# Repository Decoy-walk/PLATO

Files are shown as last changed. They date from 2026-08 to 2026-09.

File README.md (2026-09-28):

# PLATO — Embodied Memory via Material Interaction

*[한국어](README.ko.md)*

Research prototype for testing whether tactile-motor interaction with a
physical folding-block device activates procedural memory as a
supplementary channel, improving recall vs. text-only encoding. A sensing
node embedded in the folding block tracks all 20 hinges and streams the
fold state over wired USB serial to a PC bridge that logs it to CSV, git,
and/or a Google Sheet.

```
 hand  ⇄  folding block (20 flex-sensor hinges + haptic actuator)
                 │  USB serial (~20 Hz, framed 4-byte fold bitmask)
                 ▼
         bridge/plato_bridge.py  (PC)
                 │
        ┌────────┼─────────┐
        ▼        ▼         ▼
   data/*.csv   git commit   Google Sheets
```

## Hardware

| Component | Role |
|---|---|
| Seeed XIAO SAMD21 | MCU: scans the 20 hinges, drives haptic feedback, streams over USB |
| 20× flex sensor (one per hinge)  | Captures the fold sequence as the hand manipulates the block |
| 2× CD74HC4067 (16-channel analog mux) | Multiplexes 20 flex-sensor channels onto 1 ADC pin |
| Haptic/ERM motor + driver transistor | "Block + haptic feedback" condition's feedback channel |

The board was originally ESP32C3 (see git history) and moved permanently to
SAMD21. SAMD21 has no on-board radio, so wireless logging is an open
question — see "Wireless is still undecided" below — and this build uses a
wired USB serial connection as the interim transport.

### Why a mux instead of more ADC pins or an I2C ADC expander

Neither ESP32C3 nor SAMD21's XIAO form factor exposes 20 native ADC pins.
Rather than adding 5× I2C ADC boards (e.g. ADS1115), this design keeps the
channel count matched to what the board can actually do: two CD74HC4067
16-channel analog muxes (32 channels available, 20 used) share 4 address
lines and time-multiplex all 20 flex sensors onto a **single** ADC pin.
Only one mux's active-low `EN` is driven low at a time; the other's output
stays high-impedance, so both chips' common `SIG` pins can tie to the same
ADC input. Net cost: 1 ADC pin + 6 digital GPIO instead of 20 ADC pins or
extra I2C ADC hardware. (SAMD21 actually has no ADC-vs-radio pin
restriction the way ESP32C3's ADC2 did, but the mux wiring is kept
identical for continuity with the physical harness.)

### Pins (Seeed XIAO SAMD21 silkscreen labels)

| Function | XIAO pin | Notes |
|---|---|---|
| Mux common analog output | D0 (A0)  | Both CD74HC4067 `SIG` pins tie here |
| Mux address S0 | D1 | Shared between both mux chips |
| Mux address S1 | D2 | |
| Mux address S2 | D3 | |
| Mux address S3 | D4 | |
| Mux A enable (active-low) | D5 | Selects hinges 0-15 |
| Mux B enable (active-low) | D6 | Selects hinges 16-19 (channels 4-15 of mux B unused) |
| Haptic actuator PWM | D7 | To a transistor driving the ERM/LRA motor (+ flyback diode) |
| Status LED | D10 | Lit while any hinge reads folded |

Each flex sensor forms its own voltage divider into its mux channel:
`3V3 — flexSensor — muxChannel — 10kΩ — GND`. Both mux chips' `S0-S3` are
wired in parallel; `EN` pins are separate so the firmware can choose which
16-channel bank is currently driving the shared `SIG`/ADC line.

## Two separate firmware builds

- `firmware/PLATO_XIAO_SAMD21/` — the research build described below
  (SAMD21, 20-hinge sensing, wired serial, PC bridge).
- `firmware/Plato_001_fsr_led/` — the actual circuit exhibited at Maker
  Faire Tokyo 2026 (Sep 4-8): one FSR402 + one LED on a bare XIAO SAMD21,
  built for "E. Modular" (a FidgetSqueezer-style folding ball — see
  `hardware/cad/` and `hardware/docs/MFT26_devlog.pdf`). See its own README for
  the exact breadboard wiring. Kept separate from the research firmware
  since it's a different physical object (a single squeeze-force joint,
  not 20 independently-sensed hinges) built for a specific exhibition
  deadline, not the formal study.
- `firmware/Plato_002_fsr_led_buzzer_vibration/` — post-exhibition
  extension of `Plato_001_fsr_led`: adds a TMB12A05 active buzzer (5V,
  fixed ~2.4kHz, pulsed into chirps) above a squeeze-force threshold, and
  an ERM vibration-motor module whose intensity scales continuously with
  press force (a graded haptic "feel the resonance plate vibrating" layer,
  not just on/off). `Plato_001_fsr_led` is left untouched as the
  historical record of what actually showed at Maker Faire; new sensory
  layers land in their own numbered sketch instead.
- `firmware/Plato_003_fsr_led_buzzer/` — same as `Plato_002` minus the
  vibration motor module, for when only sound feedback is wanted.

## Firmware (`firmware/PLATO_XIAO_SAMD21/`)

```
PLATO_XIAO_SAMD21.ino  # setup/loop, serial commands, condition toggling
config.h                # pins, mux/timing/haptic constants, serial framing
FlexMuxManager.*        # mux channel scanning, per-hinge calibration (RAM-only), fold bitmask
HapticManager.*         # non-blocking haptic pulse control
SerialTransport.*       # wired USB serial framing (interim - see below)
sketch.yaml             # arduino-cli profile (board + platform version)
```

### Wireless is still undecided

SAMD21 has no BLE/Wi-Fi radio. Two options were on the table:

1. **Wired USB serial** (what's implemented now) — zero extra hardware,
   most reliable, but reintroduces the "does a cable undermine the
   naturalistic-interaction claim" concern raised for the write-up.
2. **External BLE UART module** (e.g. a DA14531/nRF52-based UART-BLE
   bridge) — keeps the wireless/naturalistic-use framing intact at the
   cost of extra per-node hardware and wiring.

`SerialTransport` is deliberately the only place that knows about the wire
protocol — `PLATO_XIAO_SAMD21.ino` just calls `transport.send(payload, len)`.
Swapping in a `BleUartTransport` later (same `send()` signature, framed
over a BLE UART module's serial passthrough instead of the native USB port)
should be a small, isolated change, not a rewrite.

### Calibration (per-hinge variance)

Flex-sensor voltage-divider output varies hinge-to-hinge (resistance range,
mounting preload). Rather than a single global threshold, each hinge gets
its own calibrated min/max:

- Send `c` over the serial monitor to start a 15 s calibration window
  (`CALIBRATION_DURATION_MS`); fold/unfold every hinge through its full
  range while it runs.
- Calibration is **RAM-only** (SAMD21 has no direct equivalent to ESP32's
  `Preferences`/NVS without another library dependency) and is printed
  per-hinge, so you have a `min/max/range` table to report alongside the
  data — the explicit bounding of per-hinge variance flagged as an
  internal-validity concern for the write-up. Because it's RAM-only, **run
  `c` again after every power cycle** — this matches the documented
  per-session calibration protocol anyway (run once per session/participant
  rather than trusting a stale factory default).

### Condition toggling

`h` over serial toggles haptic feedback on/off at runtime, so the same
flashed firmware serves both the **Block (motor only)** and **Block +
haptic feedback** study arms without reflashing between participants. The
condition flag is included in every serial frame (see below) so it's
logged automatically rather than needing to be tracked by hand.

### Serial frame format

Every `NOTIFY_INTERVAL_MS` (20 Hz default) the node writes a 6-byte frame
to the USB serial port: 2 marker bytes (so the PC-side reader can
byte-align on this continuous stream even if it connects mid-frame, and
self-heal from an occasional dropped/corrupted byte) followed by the same
4-byte payload the ESP32C3 build used to send over BLE:

| Byte | Content |
|---|---|
| 0 | `0xAA` sync byte 1 |
| 1 | `0x55` sync byte 2 |
| 2-4  | 20-bit fold bitmask, LSB first (bit *i* = hinge *i* folded) |
| 5 | bit0: haptic pulse currently firing · bit1: haptic-feedback condition enabled |

### Setup

```bash
arduino-cli config add board_manager.additional_urls \
  https://files.seeedstudio.com/arduino/package_seeeduino_boards_index.json
arduino-cli core update-index
arduino-cli core install Seeeduino:samd
```

`sketch.yaml` pins the board/platform version; with arduino-cli >= 0.35 the
`--profile` flag (used by the scripts below) installs and uses it
automatically. No external libraries are needed (Arduino SAMD core only).

In Arduino IDE: Tools > Board > **Seeed SAMD Boards > Seeeduino XIAO**.

### Build & flash

```bash
scripts/build.sh
scripts/upload.sh /dev/ttyACM0   # adjust to your board's serial port
scripts/monitor.sh /dev/ttyACM0
```

## PC bridge (`bridge/`)

The node streams over wired USB serial (see "Wireless is still undecided"
above); the bridge opens that port directly and fans each reading out to a
local CSV, an optional git commit+push, and/or a Google Sheet.

```bash
pip install -r bridge/requirements.txt

# CSV only:
python bridge/plato_bridge.py --ports /dev/ttyACM0

# CSV + auto-commit every 50 rows + push to Google Sheets:
python bridge/plato_bridge.py \
  --ports /dev/ttyACM0 \
  --git-commit-every 50 \
  --sheets-url "https://script.google.com/macros/s/XXXX/exec"
```

- `--ports` (default `/dev/ttyACM0`): comma-separated serial port(s), one
  per physical node — each runs in its own thread, so multiple structures
  just means multiple `--ports` entries (e.g. `/dev/ttyACM0,/dev/ttyACM1`).
- `--baud` (default 115200): must match `SERIAL_BAUD` in `config.h`.
- `--csv` (default `data/plato_log.csv`): one row per frame, columns
  `timestamp_utc,node,haptic_active,haptic_enabled,hinge_00..hinge_19`.
  Logging every snapshot (not just transitions) means one corrupted/lost
  frame never loses an event — fold-sequence order and per-hinge transition
  timing (for the Kendall's Tau / Spearman's rho / edit-distance analyses)
  are reconstructed from the time series afterward, not relied on from the
  stream itself.
- `--git-commit-every N`: commit+push the CSV every N new rows (0 disables).
  Requires the bridge to run somewhere with push access to this repo.
- `--sheets-url` / `GOOGLE_SHEETS_WEBHOOK_URL`: POSTs each row as JSON to a
  Google Apps Script Web App. See `bridge/google_apps_script.gs` for the
  script to paste into a target Sheet's Apps Script editor and deploy as a
  Web App (Extensions → Apps Script → Deploy → New deployment).

If a node disconnects mid-session, restart the bridge — it's a straight
open-and-stream loop per port, no reconnect logic yet.

## Extending

- Multiple structures/nodes: connect each over its own USB port and add it
  to `--ports`; the bridge already fans in every port concurrently.
- More/fewer hinges: `FlexMuxManager::kChannelCount` and the mux wiring
  scale to any count up to 32 (two 16-channel muxes) without firmware
  changes beyond that constant. Keep any CAD change to hinge count in sync
  with this constant (see `hardware/cad/README.md`).
- Adding wireless: implement a `BleUartTransport` with the same
  `send(data, len)` signature as `SerialTransport` and swap it in
  `PLATO_XIAO_SAMD21.ino` — the rest of the firmware doesn't need to change.

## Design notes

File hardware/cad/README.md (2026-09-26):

# CAD (Fusion 360 exports)

Fusion 360's native cloud file (`.f3d`) isn't meaningful to version in git — it's
an opaque binary tied to Autodesk's own cloud/version history, not diffable
here. Instead, export a neutral format from Fusion 360 at each milestone and
commit that:

| Format | Use for |
|---|---|
| `.step` / `.stp` | Full solid model (hinges, sensor mounts, enclosure) — preferred for anything meant to be re-opened/edited in other CAD tools |
| `.stl` | 3D-printable mesh of the current print-ready state |
| `.dxf` | 2D profiles (e.g. laser-cut hinge plates) if any part of the block is flat-stock |

## Naming convention

```
plato-block_v<major>.<minor>_<yyyy-mm-dd>.step
```

e.g. `plato-block_v0.3_2026-08-27.step`. Bump `major` on a structural change
(hinge count, layout), `minor` on a dimensional tweak (wall thickness, mount
hole size).

## Keeping CAD and firmware in sync

The physical hinge count/layout and `firmware/PLATO_XIAO_SAMD21/config.h` /
`FlexMuxManager::kChannelCount` need to agree. When exporting a new revision
that changes hinge count or numbering order, note it in the commit message
and update `kChannelCount` (and the mux wiring notes in the top-level
`README.md`) in the same PR so the two never drift apart silently.

## Wiring diagrams

Two DXF diagrams cover the same `firmware/Plato_002_fsr_led_buzzer_vibration/`
circuit (XIAO SAMD21, FSR402 voltage divider, LED, buzzer, vibration motor
module), for two different physical breadboards. Both are generated with
[ezdxf](https://ezdxf.mozman.at/) as plain vector geometry on named layers —
open either via **Insert > Insert DXF** into a Fusion 360 sketch (or any
other DXF-reading tool). Neither is a to-scale footprint layout; for the
exact row-by-row wiring instructions, see `firmware/Plato_001_fsr_led/README.md`
and `firmware/Plato_002_fsr_led_buzzer_vibration/README.md`.

- **`plato_002_wiring_diagram.dxf`** — matches the **no-rail mini
  breadboard** the firmware READMEs document: 3V3/GND are net labels only,
  and every use of them is its own point-to-point jumper back to the chip
  (no shared rail exists on that board). Layers: `WIRES`, `COMPONENTS`,
  `RAILS`, `LABELS`.
- **`plato_002_wiring_diagram_shared_rail.dxf`** — redrawn for a
  **standard breadboard with real +/- power rails**: the chip only needs
  ONE jumper to the +rail and ONE to the -rail; every component taps the
  rail directly instead of getting its own dedicated wire back to the
  chip. Simpler to build if you're not constrained to the small no-rail
  board. Layers: `WIRES`, `COMPONENTS`, `RAIL_PLUS`, `RAIL_MINUS`, `LABELS`.

Pick whichever matches the physical breadboard actually on hand — they're
electrically equivalent, just wired differently.

## Adding a new export

From your local machine (this repo isn't checked out where Fusion 360 runs):

```bash
git add hardware/cad/plato-block_vX.Y_YYYY-MM-DD.step
git commit -m "Add CAD export vX.Y: <what changed>"
git push
```

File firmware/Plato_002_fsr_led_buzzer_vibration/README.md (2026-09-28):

# Plato_002_fsr_led_buzzer_vibration (Seeeduino XIAO, SAMD21)

Extends `Plato_001_fsr_led` (the circuit actually exhibited at Maker Faire
Tokyo 2026) with two more outputs, both active once the FSR is squeezed
past a threshold:

- A buzzer (TMB12A05) — a discrete on/off chirp layer (see below).
- A vibration-motor breakout module (driver built into the module) shaking
  hard enough to rattle the printed plastic structure against itself, and
  standing in for "feel the resonance plate vibrating" — its intensity
  scales continuously with how hard you press, not just on/off.

The FSR→LED brightness response is unchanged and stays continuously
proportional to force. The buzzer's chirp is a discrete on/off layer on
top, since "buzz" is a discrete effect, not something meaningfully swept
by force the way LED brightness is. The vibration motor, on the other
hand, is graded like the LED — see "Haptic feel" below.

## The buzzer is an active buzzer, not a passive piezo

TMB12A05 has a built-in driver and a fixed ~2.4kHz internal tone, rated
**4-8V (5V nominal)**. Two consequences that weren't obvious from the part
just looking like "a buzzer":

1. **Its pitch isn't settable.** `tone(pin, frequency)` only works on a bare
   passive piezo element; on an active buzzer like this one, any signal
   that turns it on just makes it sound at its own fixed ~2.4kHz — you
   can't dial in an arbitrary frequency.
2. **It needs 5V, not 3.3V, to reliably start.** Below its ~4V minimum, the
   internal driver likely won't oscillate at all — silence, not a quiet
   tone. Wiring its `+` lead to the XIAO's 3.3V rail (the natural thing to
   do next to the FSR/LED circuit, which does run at 3.3V) is almost
   certainly why the buzzer doesn't respond.

Since the MCU's GPIO HIGH is only 3.3V, it can't source the required 5V
either, so this build wires the buzzer as a **low-side switch**:

```
XIAO "5V" pin --------> buzzer + lead
buzzer - lead --------> D8
```

(The `5V` pin sources USB's raw 5V when the board is powered over USB —
this wiring only works while USB-powered, not on battery/regulated-3.3V-only
power.)

> **Lead identification: the SHORT lead is `+`, the LONG lead is `-`** —
> backwards from the LED long-leg-is-anode convention, easy to get wrong by
> habit. A printed `+` on the case can also fall off or be inconsistently
> placed, so trust lead length over any marking. Reversed polarity can
> prevent the buzzer from working at all.

For ON, `D8` is driven `OUTPUT` `LOW`, sinking current and completing the
circuit. For OFF, **`D8` is switched to `INPUT` (high-impedance)**, not
driven `HIGH` — driving it `HIGH` only leaves ~1.7V across the buzzer
(5V - 3.3V), and this particular buzzer's driver IC can *sustain*
oscillation at that leftover voltage even though it needs the full 4V+ to
*start* it, so a once-triggered buzzer never actually stopped when tried
with `HIGH` instead. Switching to `INPUT` removes the current path
entirely, which reliably silences it with no extra hardware. The firmware
does this (`pinMode(buzzerPin, OUTPUT/INPUT)` + `digitalWrite(buzzerPin, LOW)`
for ON, not `tone()`/`noTone()` and not a plain `HIGH` for OFF).

The buzzer draws ~30mA when on. Driving that directly through a GPIO pin as
a sink is common practice for a small load like this. If you have a small
NPN transistor (e.g. 2N3904) on hand, using it as a true low-side switch
(`D8` → base through a ~1kΩ resistor, buzzer `-` lead → collector, emitter
→ GND, control logic flipped back to `HIGH`=on) is an equally valid
alternative to the `INPUT`-for-off trick above and keeps current off the
MCU pin entirely — but isn't required to fix the "won't turn off" symptom.

## Making the buzzer sound less harsh (chirp pattern, no new hardware)

TMB12A05's ~2.4kHz tone is generated by its own internal driver IC — the
firmware has no control over that pitch or waveform at all (`tone()`'s
frequency argument does nothing here; see above). What the firmware *can*
control is the on/off **rhythm**: instead of holding the buzzer on
continuously for the whole press (one flat, harsh drone), it now pulses it
into short chirps while pressed — `BUZZ_ON_MS` (90ms) on, `BUZZ_OFF_MS`
(35ms) off, repeating — which reads as a beeping pattern rather than a
continuous industrial buzz. Each chirp's OFF gap still uses the same
`INPUT` high-impedance trick (not `HIGH`), so it's reliably silent between
chirps too.

An earlier, shorter version of this pattern (25ms on / 70ms off) came out
noticeably **quieter** than the old continuous tone, for two compounding
reasons: a low `ON/(ON+OFF)` duty cycle (26%) lowers the time-averaged
loudness on its own, and cutting the pulse at 25ms may also stop it before
the buzzer's internal driver finishes ramping up to full amplitude, so
each chirp never even reached full volume. 90/35 (72% duty) fixes both —
still audibly pulsing, not a flat drone, but full-volume and much louder.

This needed the main loop restructured from a single blocking `delay(50)`
per iteration to `millis()`-timed scheduling, so the buzzer can pulse
faster (down to a few ms) than the 50ms FSR/LED sampling rate allows —
sensor sampling and LED brightness are otherwise unchanged, still
effectively running at the same ~20Hz rate.

Tune `BUZZ_ON_MS` / `BUZZ_OFF_MS` in the `.ino` to taste: shorter ON / longer
OFF reads as a lighter "tick"; longer ON / shorter OFF drifts back towards a
continuous drone. **PWMing the sink pin** (partial duty via `analogWrite`
instead of full `LOW`/`INPUT`) was considered for a smoother fade, but
rejected: the leftover voltage during the `HIGH` portion of a PWM cycle can
re-trigger the exact "won't turn off" sustain behavior described above, so
this build only ever drives the pin fully `LOW` (on) or fully `INPUT` (off).

If you want a genuinely different pitch — e.g. closer to 600Hz — or a
smoother (less buzzy) waveform, that requires different hardware: swap this
active buzzer for a **passive piezo** (a 2-lead disc with no built-in
driver IC), which lets `tone(buzzerPin, 600)` set an arbitrary frequency
directly and runs fine off 3.3V (no `5V` pin/low-side-switch wiring needed
at all). That's a separate hardware change, not something this sketch's
software can do with the TMB12A05 installed.

## Haptic feel: force-proportional vibration, not on/off

The vibration motor module wraps a small **ERM (eccentric rotating mass)**
motor, not an LRA (linear resonant actuator). That distinction matters for
how it's driven:

- An LRA is driven at (or swept across) a specific resonant frequency, and
  its *frequency* is the tunable knob.
- An ERM has no such tunable frequency. What you feel as its "buzz
  frequency" is just how fast the offset weight is spinning, which tracks
  the applied voltage/PWM duty directly — there's no separate frequency
  control, only a speed/intensity control.

Small coin ERM motors also typically need roughly **60-70% of their rated
voltage just to start spinning at all** (they have to overcome their own
static friction/cogging) — below that they don't spin, so they give no
felt vibration rather than a gentler one. That makes a naive full 0-255
PWM sweep (like the LED's brightness mapping) mostly waste: most of that
range would either not move the motor or move it so weakly it can't be
felt.

So instead, once pressed, intensity is mapped from `MIN_EFFECTIVE_VIBRATION`
(170, ≈67% duty) up to `MAX_VIBRATION` (255) across the pressed force range
— never dropping into the ineffective low band — so a light press still
gives a felt, near-full-speed buzz and a hard press gives the strongest
one, rather than a binary "vibrating or not." This also keeps it running
close to its rated speed most of the time, which is roughly where small
coin ERM motors' felt vibration frequency sits — commonly cited around
**~150-200Hz** for this class of part at rated voltage, though that number
depends on the exact motor and isn't something this build measured
directly (re-check against a datasheet if you know this module's part
number).

## What this doesn't do yet: Chladni/Cymatics patterns

The original three-part plan also called for mapping the sound to visible
Chladni-figure/Cymatics patterns. Neither this active buzzer (fixed
~2.4kHz, no frequency sweep possible) nor the ERM vibration motor has the
frequency control or power to drive visible nodal-line patterns in sand on
a plate — a real Chladni setup needs an amplified, frequency-swept signal
into a rigidly-mounted plate via a proper exciter/bass shaker. This build
treats the buzzer+vibration as a conceptual/experiential stand-in (press →
hear + feel + hear-the-structure-rattle) rather than a literal Chladni
demo. If a real visual pattern is wanted later, that's a separate hardware
addition (audio amp + exciter, or a software visualization driven by a mic
input) — flag it as its own task rather than folding it into this sketch.

## Wiring (no-rail mini breadboard)

Builds on the `Plato_001_fsr_led` breadboard (FSR on A0, LED on D9, rows
A-G — see that folder's README). This board has no shared power rails, so
every use of a supply voltage is its own point-to-point jumper back to its
source:

14. `D8` --jumper--> row H
15. Buzzer `-` lead (**long** lead) → row H
16. Buzzer `+` lead (**short** lead) → row I
17. XIAO `5V` pin --jumper--> row I
18. `D2` --jumper--> row J
19. Vibration module `IN` → row J
20. `3.3V-OUT` --jumper--> row K
21. Vibration module `VCC` → row K
22. `GND` --jumper--> row L
23. Vibration module `GND` → row L

**Buzzer** (TMB12A05, active, 2 leads): `+` (short) lead → row I (→ XIAO
`5V` pin), `-` (long) lead → row H (→ `D8`, `OUTPUT LOW`/`INPUT` switching — see above).

**Vibration motor module** (3-pin breakout, driver already on the board):
`D2` → `IN` (row J), `3V3` → `VCC` (row K, module is commonly rated 3-5V;
expect less punch at 3.3V than at 5V — try raising `MAX_VIBRATION` towards
255 (already its default) first before reaching for a 5V source), `GND` →
`GND` (row L).

## Wiring (standard breadboard with +/- power rails)

If you're not constrained to the no-rail mini board, a standard breadboard
with power rails is simpler to build: the chip needs only **one** jumper to
the +rail and **one** to the -rail total (plus the buzzer's dedicated 5V
jumper below, since that's a different voltage than the +rail), and every
other component taps a rail directly instead of getting its own dedicated
wire back to the chip. See `hardware/cad/plato_002_wiring_diagram_shared_rail.dxf`
for the layout, which includes the buzzer's dedicated 5V feed.

1. `3.3V-OUT` --jumper--> breadboard **+rail**
2. `GND` --jumper--> breadboard **-rail**
3. FSR402 leg 1 → +rail; leg 2 → node C
4. 1kΩ resistor leg 1 → node C; leg 2 → -rail
5. `A0` --jumper--> node C (the divider tap point)
6. `D9` → 330Ω resistor leg 1; leg 2 → LED anode; LED cathode → -rail
7. XIAO `5V` pin → buzzer `+` lead (**short**); buzzer `-` lead (**long**) → `D8`
8. `D2` → vibration module `IN`
9. Vibration module `VCC` → +rail
10. Vibration module `GND` → -rail

## Tuning

- `PRESS_ON_BRIGHTNESS` / `PRESS_OFF_BRIGHTNESS` (40 / 20): hysteresis
  thresholds on the same 0-255 brightness scale as the LED — widen the gap
  if the buzzer/vibration chatter on and off near the threshold.
- `MIN_EFFECTIVE_VIBRATION` / `MAX_VIBRATION` (170 / 255): the PWM range the
  vibration module's `IN` pin is scaled across while pressed — see "Haptic
  feel" above. Raise `MIN_EFFECTIVE_VIBRATION` if a light press still
  doesn't spin the motor at all; lower it (cautiously) if you want a
  softer floor and your motor tolerates it.
- `BUZZ_ON_MS` / `BUZZ_OFF_MS` (90 / 35): the buzzer's chirp pattern while
  pressed — see "Making the buzzer sound less harsh" above. Raise `BUZZ_ON_MS`
  and/or lower `BUZZ_OFF_MS` for louder/more continuous; lower `BUZZ_ON_MS`
  and/or raise `BUZZ_OFF_MS` for softer/more clearly pulsed. Practical
  bench-tested bounds (not datasheet specs — TMB12A05 doesn't publish
  ramp-up/decay times):
  - `BUZZ_ON_MS` below ~40-50ms: driver may cut off before reaching full
    volume (this is what made the original 25ms version sound quiet/thin).
    Above ~150-200ms: no technical ceiling, but it starts reading as one
    continuous tone rather than distinct beeps.
  - `BUZZ_OFF_MS` at 0: reverts to the original harsh continuous drone
    (no audible gap at all). Below ~15-20ms: the buzzer's diaphragm may not
    fully settle before the next pulse starts, so the gap barely registers.
    Above ~300-500ms: reads as separate, clearly spaced clicks, and a very
    short press can end before a single chirp completes.

  | Goal | ON / OFF (ms) | Duty |
  |------|---------------|------|
  | Softest (ok if quiet) | 40 / 150 | ~21% |
  | Current default (balanced) | 90 / 35 | ~72% |
  | Loud, distinct beeps | 120 / 60 | ~67% |
  | Near-continuous (loud, harsh) | 200 / 10 | ~95% |

## Setup / build / flash

Same as `Plato_001_fsr_led` — see that folder's README (Seeeduino:samd
board package, no external libraries).

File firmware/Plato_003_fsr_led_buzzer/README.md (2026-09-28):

# Plato_003_fsr_led_buzzer (Seeeduino XIAO, SAMD21)

Extends `Plato_001_fsr_led` (the circuit actually exhibited at Maker Faire
Tokyo 2026) with one more output, triggered when the FSR is squeezed past
a threshold: a buzzer (TMB12A05). Same as
`Plato_002_fsr_led_buzzer_vibration` but **without the vibration motor
module** — use this if you only want sound feedback.

The FSR→LED brightness response is unchanged and stays continuously
proportional to force; the buzzer is a separate on/off layer on top, since
"buzz" is a discrete effect, not something meaningfully swept by force the
way LED brightness is.

## The buzzer is an active buzzer, not a passive piezo

TMB12A05 has a built-in driver and a fixed ~2.4kHz internal tone, rated
**4-8V (5V nominal)**. Two consequences that weren't obvious from the part
just looking like "a buzzer":

1. **Its pitch isn't settable.** `tone(pin, frequency)` only works on a bare
   passive piezo element; on an active buzzer like this one, any signal
   that turns it on just makes it sound at its own fixed ~2.4kHz — you
   can't dial in an arbitrary frequency.
2. **It needs 5V, not 3.3V, to reliably start.** Below its ~4V minimum, the
   internal driver likely won't oscillate at all — silence, not a quiet
   tone. Wiring its `+` lead to the XIAO's 3.3V rail (the natural thing to
   do next to the FSR/LED circuit, which does run at 3.3V) is almost
   certainly why a buzzer wired that way doesn't respond.

Since the MCU's GPIO HIGH is only 3.3V, it can't source the required 5V
either, so this build wires the buzzer as a **low-side switch**:

```
XIAO "5V" pin --------> buzzer + lead
buzzer - lead --------> D8
```

(The `5V` pin sources USB's raw 5V when the board is powered over USB —
this wiring only works while USB-powered, not on battery/regulated-3.3V-only
power.)

> **Lead identification: the SHORT lead is `+`, the LONG lead is `-`** —
> backwards from the LED long-leg-is-anode convention, easy to get wrong by
> habit. A printed `+` on the case can also fall off or be inconsistently
> placed, so trust lead length over any marking. Reversed polarity can
> prevent the buzzer from working at all.

For ON, `D8` is driven `OUTPUT` `LOW`, sinking current and completing the
circuit. For OFF, **`D8` is switched to `INPUT` (high-impedance)**, not
driven `HIGH` — driving it `HIGH` only leaves ~1.7V across the buzzer
(5V - 3.3V), and this particular buzzer's driver IC can *sustain*
oscillation at that leftover voltage even though it needs the full 4V+ to
*start* it, so a once-triggered buzzer never actually stopped when tried
with `HIGH` instead. Switching to `INPUT` removes the current path
entirely, which reliably silences it with no extra hardware. The firmware
does this (`pinMode(buzzerPin, OUTPUT/INPUT)` + `digitalWrite(buzzerPin, LOW)`
for ON, not `tone()`/`noTone()` and not a plain `HIGH` for OFF).

The buzzer draws ~30mA when on. Driving that directly through a GPIO pin as
a sink is common practice for a small load like this. If you have a small
NPN transistor (e.g. 2N3904) on hand, using it as a true low-side switch
(`D8` → base through a ~1kΩ resistor, buzzer `-` lead → collector, emitter
→ GND, control logic flipped back to `HIGH`=on) is an equally valid
alternative to the `INPUT`-for-off trick above and keeps current off the
MCU pin entirely — but isn't required to fix the "won't turn off" symptom.

## Making the buzzer sound less harsh (chirp pattern, no new hardware)

TMB12A05's ~2.4kHz tone is generated by its own internal driver IC — the
firmware has no control over that pitch or waveform at all (`tone()`'s
frequency argument does nothing here; see above). What the firmware *can*
control is the on/off **rhythm**: instead of holding the buzzer on
continuously for the whole press (one flat, harsh drone), it now pulses it
into short chirps while pressed — `BUZZ_ON_MS` (90ms) on, `BUZZ_OFF_MS`
(35ms) off, repeating — which reads as a beeping pattern rather than a
continuous industrial buzz. Each chirp's OFF gap still uses the same
`INPUT` high-impedance trick (not `HIGH`), so it's reliably silent between
chirps too.

An earlier, shorter version of this pattern (25ms on / 70ms off) came out
noticeably **quieter** than the old continuous tone, for two compounding
reasons: a low `ON/(ON+OFF)` duty cycle (26%) lowers the time-averaged
loudness on its own, and cutting the pulse at 25ms may also stop it before
the buzzer's internal driver finishes ramping up to full amplitude, so
each chirp never even reached full volume. 90/35 (72% duty) fixes both —
still audibly pulsing, not a flat drone, but full-volume and much louder.

This needed the main loop restructured from a single blocking `delay(50)`
per iteration to `millis()`-timed scheduling, so the buzzer can pulse
faster (down to a few ms) than the 50ms FSR/LED sampling rate allows —
sensor sampling and LED brightness are otherwise unchanged, still
effectively running at the same ~20Hz rate.

Tune `BUZZ_ON_MS` / `BUZZ_OFF_MS` in the `.ino` to taste: shorter ON / longer
OFF reads as a lighter "tick"; longer ON / shorter OFF drifts back towards a
continuous drone. **PWMing the sink pin** (partial duty via `analogWrite`
instead of full `LOW`/`INPUT`) was considered for a smoother fade, but
rejected: the leftover voltage during the `HIGH` portion of a PWM cycle can
re-trigger the exact "won't turn off" sustain behavior described above, so
this build only ever drives the pin fully `LOW` (on) or fully `INPUT` (off).

If you want a genuinely different pitch — e.g. closer to 600Hz — or a
smoother (less buzzy) waveform, that requires different hardware: swap this
active buzzer for a **passive piezo** (a 2-lead disc with no built-in
driver IC), which lets `tone(buzzerPin, 600)` set an arbitrary frequency
directly and runs fine off 3.3V (no `5V` pin/low-side-switch wiring needed
at all). That's a separate hardware change, not something this sketch's
software can do with the TMB12A05 installed.

## Wiring (no-rail mini breadboard)

Builds on the `Plato_001_fsr_led` breadboard (FSR on A0, LED on D9, rows
A-G — see that folder's README). This board has no shared power rails, so
every use of a supply voltage is its own point-to-point jumper back to its
source:

14. `D8` --jumper--> row H
15. Buzzer `-` lead (**long** lead) → row H
16. Buzzer `+` lead (**short** lead) → row I
17. XIAO `5V` pin --jumper--> row I

**Buzzer** (TMB12A05, active, 2 leads): `+` (short) lead → row I (→ XIAO
`5V` pin), `-` (long) lead → row H (→ `D8`, `OUTPUT LOW`/`INPUT` switching — see above).

## Wiring (standard breadboard with +/- power rails)

If you're not constrained to the no-rail mini board: the chip needs only
**one** jumper to the +rail and **one** to the -rail total for the FSR/LED
circuit (plus the buzzer's dedicated 5V jumper, since that's a different
voltage than the +rail), and every other component taps a rail directly
instead of getting its own dedicated wire back to the chip.

1. `3.3V-OUT` --jumper--> breadboard **+rail**
2. `GND` --jumper--> breadboard **-rail**
3. FSR402 leg 1 → +rail; leg 2 → node C
4. 1kΩ resistor leg 1 → node C; leg 2 → -rail
5. `A0` --jumper--> node C (the divider tap point)
6. `D9` → 330Ω resistor leg 1; leg 2 → LED anode; LED cathode → -rail
7. XIAO `5V` pin → buzzer `+` lead (**short**); buzzer `-` lead (**long**) → `D8`

## Tuning

- `PRESS_ON_BRIGHTNESS` / `PRESS_OFF_BRIGHTNESS` (40 / 20): hysteresis
  thresholds on the same 0-255 brightness scale as the LED — widen the gap
  if the buzzer chatters on and off near the threshold.
- `condMin` / `condMax`: FSR402 conductance range, re-measure per physical
  build (see `Plato_001_fsr_led/README.md`'s calibration section).
- `BUZZ_ON_MS` / `BUZZ_OFF_MS` (90 / 35): the buzzer's chirp pattern while
  pressed — see "Making the buzzer sound less harsh" above. Raise `BUZZ_ON_MS`
  and/or lower `BUZZ_OFF_MS` for louder/more continuous; lower `BUZZ_ON_MS`
  and/or raise `BUZZ_OFF_MS` for softer/more clearly pulsed. Practical
  bench-tested bounds (not datasheet specs — TMB12A05 doesn't publish
  ramp-up/decay times):
  - `BUZZ_ON_MS` below ~40-50ms: driver may cut off before reaching full
    volume (this is what made the original 25ms version sound quiet/thin).
    Above ~150-200ms: no technical ceiling, but it starts reading as one
    continuous tone rather than distinct beeps.
  - `BUZZ_OFF_MS` at 0: reverts to the original harsh continuous drone
    (no audible gap at all). Below ~15-20ms: the buzzer's diaphragm may not
    fully settle before the next pulse starts, so the gap barely registers.
    Above ~300-500ms: reads as separate, clearly spaced clicks, and a very
    short press can end before a single chirp completes.

  | Goal | ON / OFF (ms) | Duty |
  |------|---------------|------|
  | Softest (ok if quiet) | 40 / 150 | ~21% |
  | Current default (balanced) | 90 / 35 | ~72% |
  | Loud, distinct beeps | 120 / 60 | ~67% |
  | Near-continuous (loud, harsh) | 200 / 10 | ~95% |

## Setup / build / flash

Same as `Plato_001_fsr_led` — see that folder's README (Seeeduino:samd
board package, no external libraries).

## Adding the vibration module back

See `firmware/Plato_002_fsr_led_buzzer_vibration/` — same circuit plus a
3-pin vibration motor module on `D2`.

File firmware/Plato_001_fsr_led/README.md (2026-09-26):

# Plato_001_fsr_led (Seeeduino XIAO, SAMD21)

The actual circuit built and exhibited at Maker Faire Tokyo 2026
(Sep 4-8) as the interactive element of "E. Modular" — a FidgetSqueezer-
style folding ball assembled from 3D-printed hinge modules and rubber
bands (see `hardware/cad/` and `hardware/docs/MFT26_devlog.pdf`). One FSR402
at a joint reads squeeze force; one LED brightens in response. This is a
separate, minimal build from `firmware/PLATO_XIAO_SAMD21/` (the 20-hinge
research firmware) — different physical object, different purpose.

## Wiring

No-rail mini breadboard, XIAO SAMD21 straddling the middle:

**FSR circuit** (chip's left side, `A0`):

| Step | Connection |
|---|---|
| 1 | Jumper: `3V3-OUT` (chip right side) → row B |
| 2 | FSR402 leg 1 → row B |
| 3 | FSR402 leg 2 → row C |
| 4 | 1kΩ resistor leg 1 → row C (voltage-divider junction) |
| 5 | 1kΩ resistor leg 2 → row D |
| 6 | Jumper: `GND` (chip right side) → row D |
| 7 | Jumper: `A0` (chip left side) → row C (the divider tap point) |

**LED circuit** (chip's right side, `D9`):

| Step | Connection |
|---|---|
| 8 | Jumper: `D9` → row E |
| 9 | 330Ω resistor leg 1 → row E |
| 10 | 330Ω resistor leg 2 → row F |
| 11 | LED anode (long leg) → row F |
| 12 | LED cathode (short leg) → row G |
| 13 | Jumper: `GND` → row G |

Row C must contain exactly three things: FSR leg 2, the 1kΩ resistor's
first leg, and the A0 jumper — that's the voltage-divider tap point. Row B
(power) and row G (LED ground) each need their own separate 3.3V/GND
jumper, since this board has no shared power rails.

## Setup

```bash
arduino-cli config add board_manager.additional_urls \
  https://files.seeedstudio.com/arduino/package_seeeduino_boards_index.json
arduino-cli core update-index
arduino-cli core install Seeeduino:samd
```

In Arduino IDE: Tools > Board > **Seeed SAMD Boards > Seeeduino XIAO**.

## Build & flash

```bash
arduino-cli compile --fqbn Seeeduino:samd:seeed_XIAO_m0 .
arduino-cli upload --fqbn Seeeduino:samd:seeed_XIAO_m0 -p /dev/ttyACM0 .
```

No external libraries — Arduino SAMD core only.

## Calibrating `condMin` / `condMax`

Open the serial monitor at 9600 baud. With nothing touching the FSR, note
the printed `conductance` (should be near `condMin`); squeeze at the
hardest force you expect at the exhibit and note that value for
`condMax`. Re-measure per physical build — grip strength, mounting
pressure, and the individual FSR sample all shift this range.

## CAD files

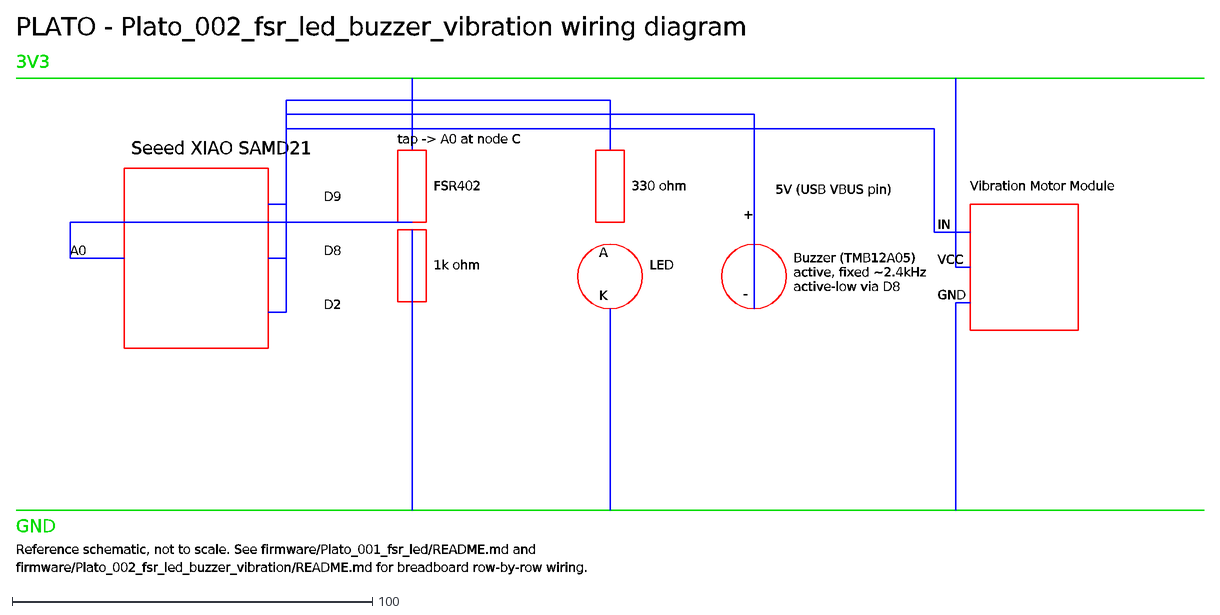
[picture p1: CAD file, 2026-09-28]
hardware/cad/plato_002_wiring_diagram.dxf
3V3
GND
Seeed XIAO SAMD21
A0
D9
D8
D2
FSR402
1k ohm
tap -> A0 at node C
330 ohm
LED
A
K
5V (USB VBUS pin)
+
Buzzer (TMB12A05)
active, fixed ~2.4kHz
active-low via D8
-
Vibration Motor Module
IN
VCC
PLATO - Plato_002_fsr_led_buzzer_vibration wiring diagram
Reference schematic, not to scale. See firmware/Plato_001_fsr_led/README.md and
firmware/Plato_002_fsr_led_buzzer_vibration/README.md for breadboard row-by-row wiring.

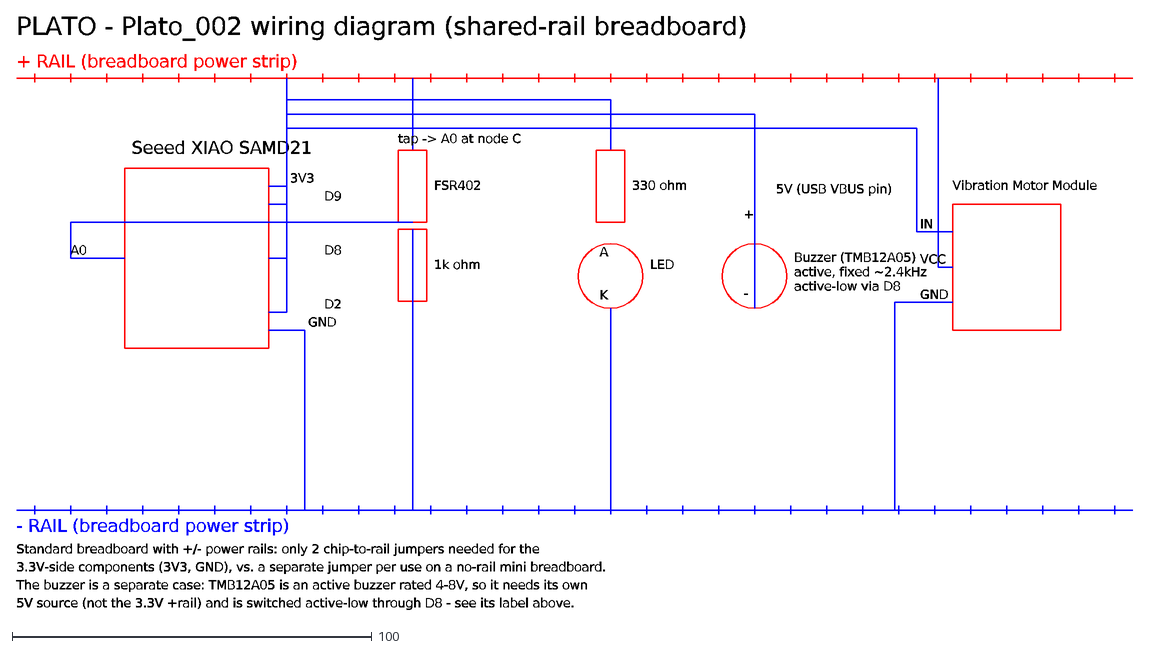
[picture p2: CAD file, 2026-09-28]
hardware/cad/plato_002_wiring_diagram_shared_rail.dxf
+ RAIL (breadboard power strip)
- RAIL (breadboard power strip)
Seeed XIAO SAMD21
A0
D9
D8
D2
3V3
GND
FSR402
1k ohm
tap -> A0 at node C
330 ohm
LED
A
K
5V (USB VBUS pin)
+
Buzzer (TMB12A05)
active, fixed ~2.4kHz
active-low via D8
-
Vibration Motor Module
IN
VCC
PLATO - Plato_002 wiring diagram (shared-rail breadboard)
Standard breadboard with +/- power rails: only 2 chip-to-rail jumpers needed for the
3.3V-side components (3V3, GND), vs. a separate jumper per use on a no-rail mini breadboard.
The buzzer is a separate case: TMB12A05 is an active buzzer rated 4-8V, so it needs its own
5V source (not the 3.3V +rail) and is switched active-low through D8 - see its label above.

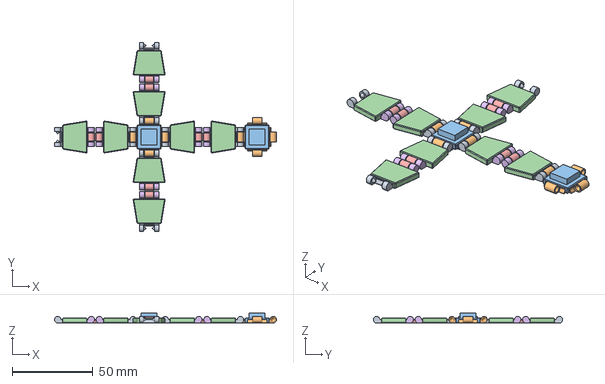
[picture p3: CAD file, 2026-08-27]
hardware/cad/plato-block_v0.1_2026-08-27.step
137.9 x 117.5 x 6.00 mm

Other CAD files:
hardware/cad/plato-block_v0.1_2026-08-27.stl

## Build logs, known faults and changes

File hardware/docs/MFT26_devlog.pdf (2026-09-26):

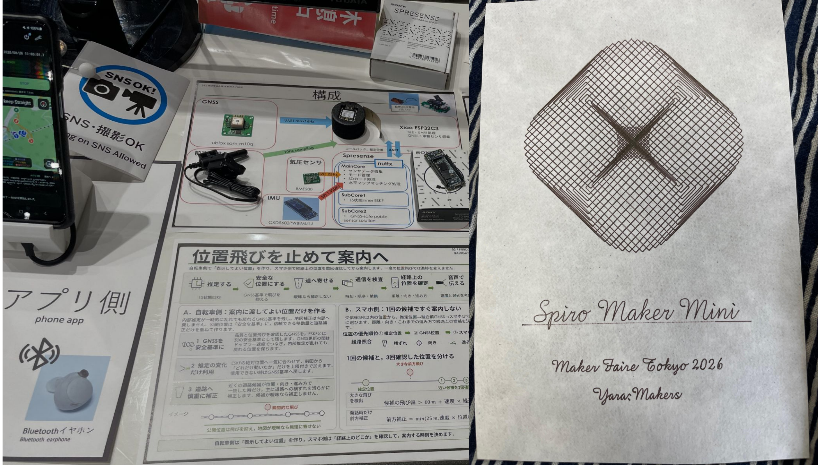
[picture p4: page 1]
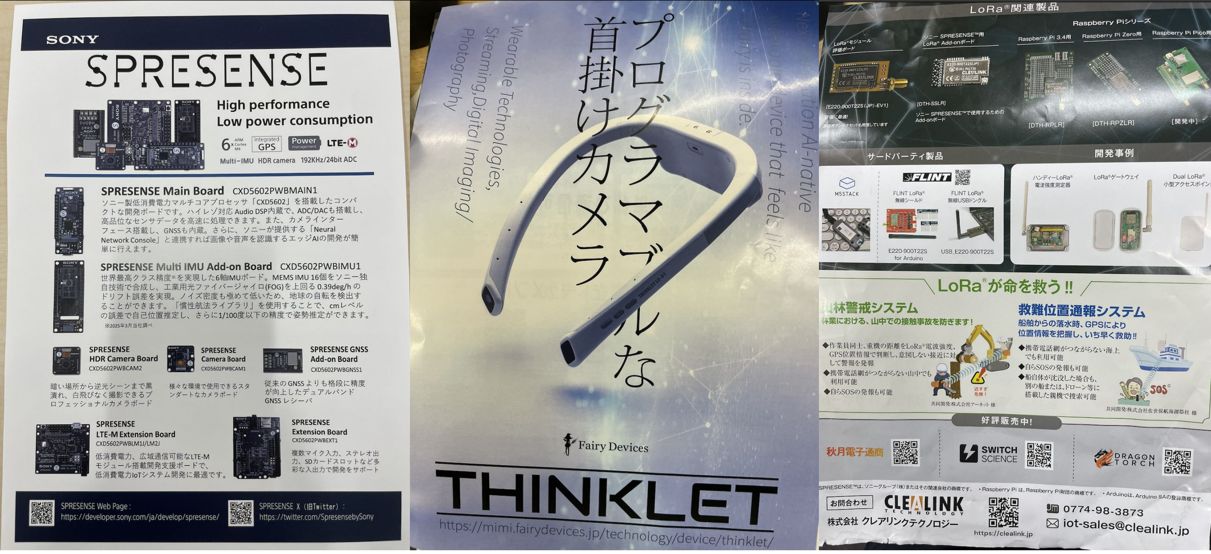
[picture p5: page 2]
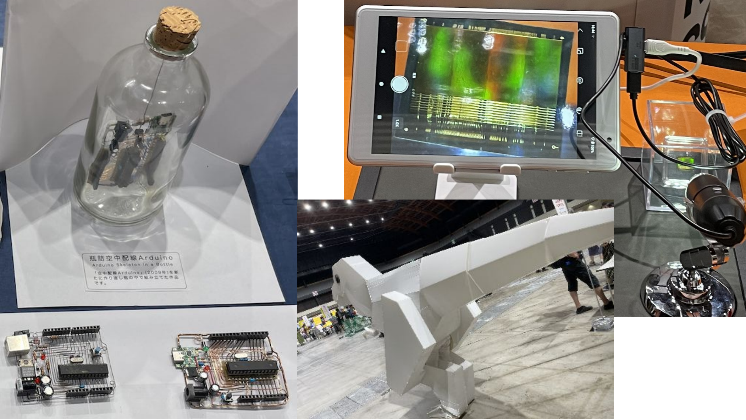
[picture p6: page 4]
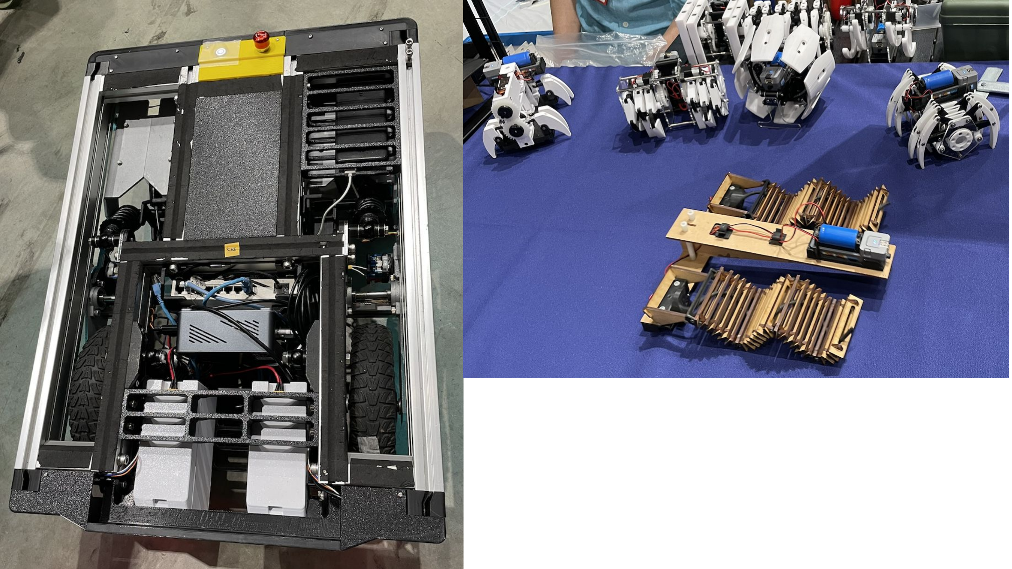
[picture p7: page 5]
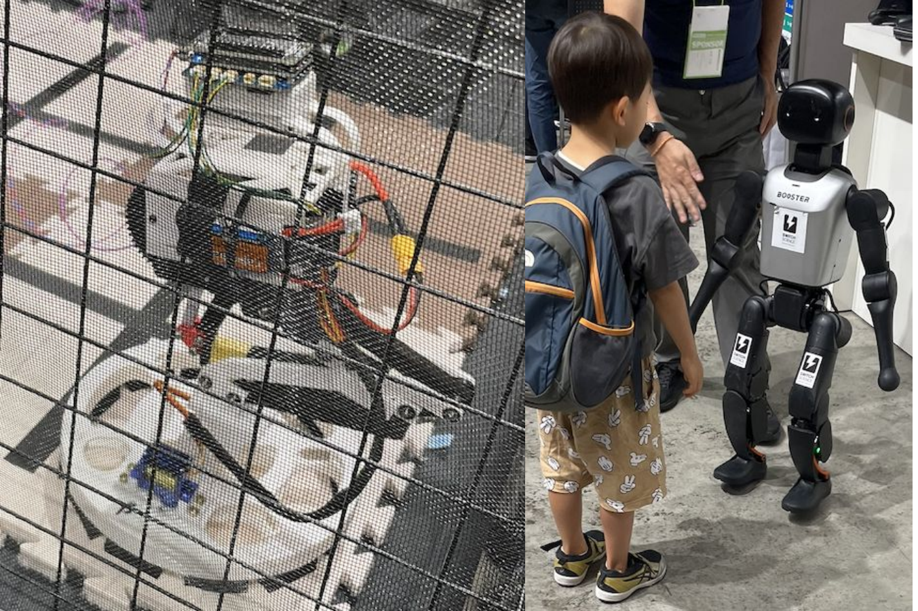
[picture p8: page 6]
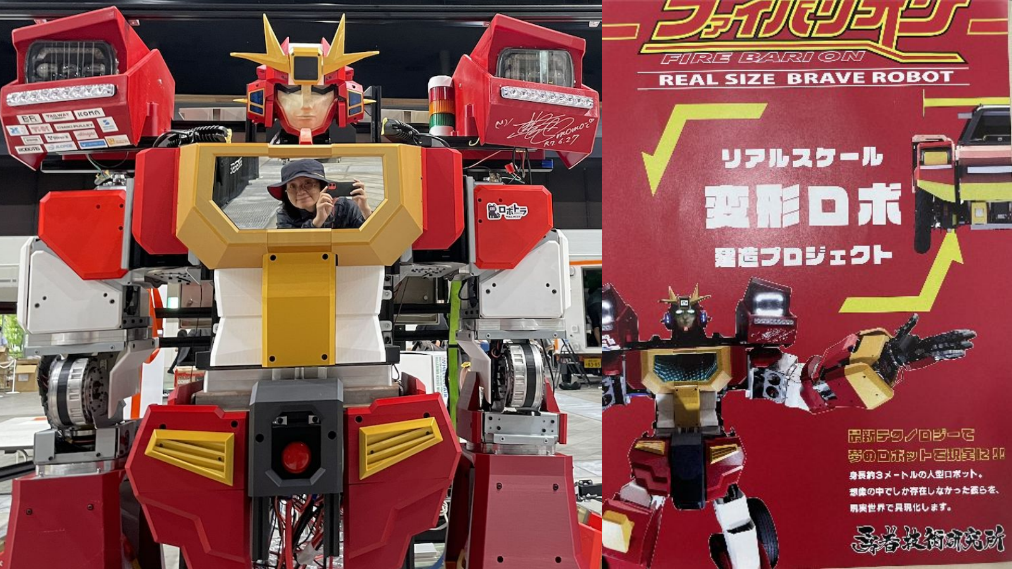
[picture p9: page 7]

This thing was created by kyunghee YOO and is the property of FUTURE CRAFT

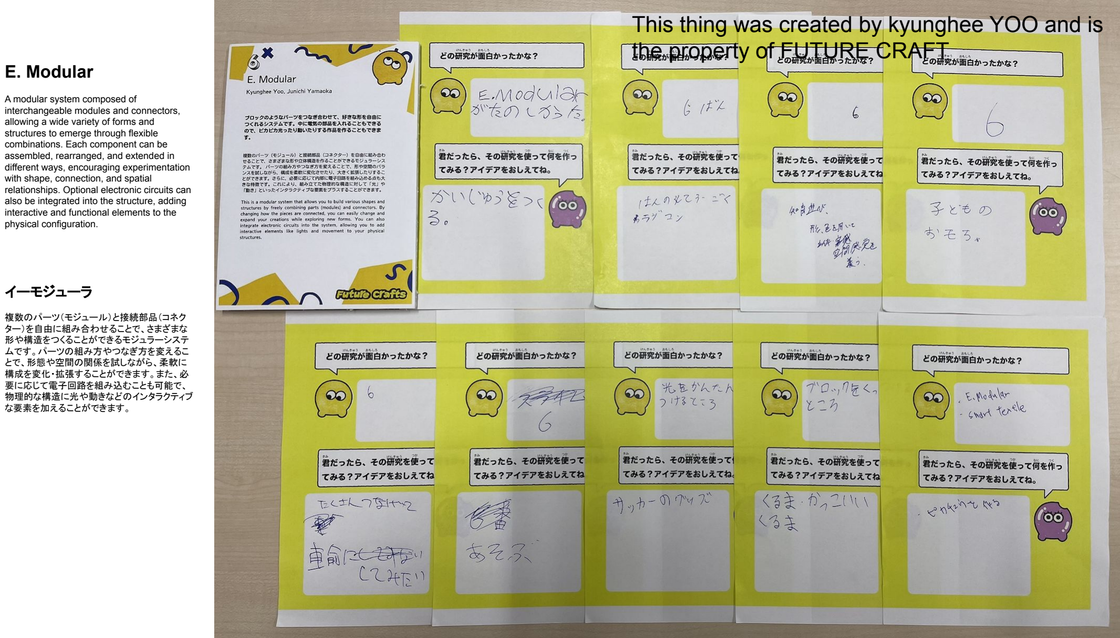
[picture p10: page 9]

the property of FUTURE CRAFT
E. Modular

A modular system composed of interchangeable modules and connectors, allowing a wide variety of forms and structures to emerge through flexible combinations. Each component can be assembled, rearranged, and extended in different ways, encouraging experimentation with shape, connection, and spatial relationships. Optional electronic circuits can also be integrated into the structure, adding interactive and functional elements to the physical configuration.

イーモジューラ

複数のパーツ（モジュール）と接続部品（コネク
ター）を自由に組み合わせることで、さまざまな
形や構造をつくることができるモジュラーシステ
ムです。パーツの組み方やつなぎ方を変えるこ
とで、形態や空間の関係を試しながら、柔軟に
構成を変化・拡張することができます。また、必
要に応じて電子回路を組み込むことも可能で、
物理的な構造に光や動きなどのインタラクティブ
な要素を加えることができます。

# Sep 8 - Maker Fair Tokyo Day2

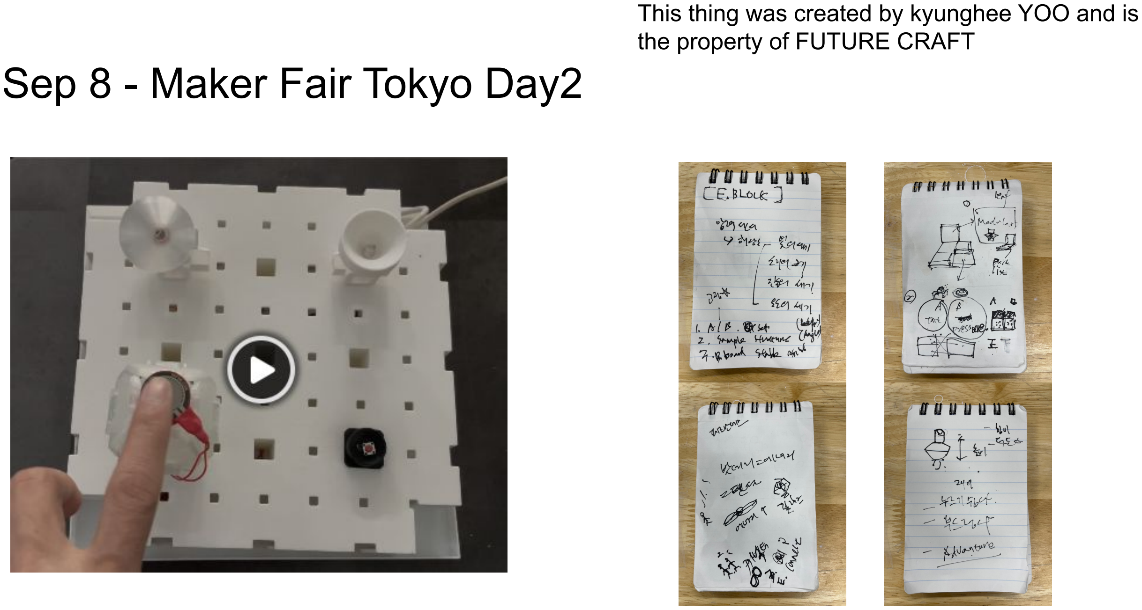
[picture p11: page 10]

the property of FUTURE CRAFT

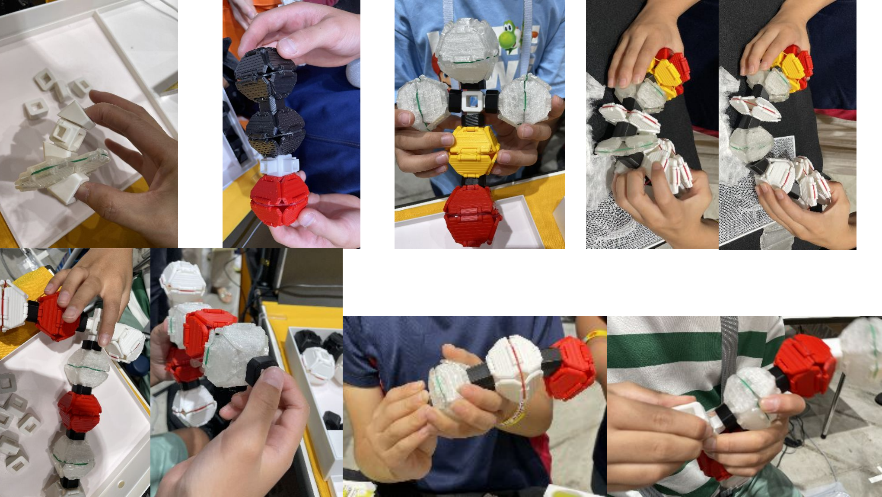
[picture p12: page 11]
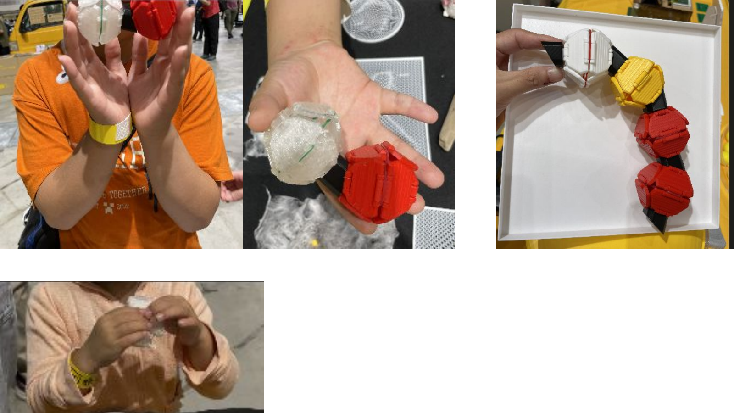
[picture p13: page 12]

# Sep 5 - Maker Fair Tokyo Day1

the property of FUTURE CRAFT

1.

# Sep 4 - Booth Setup Day0

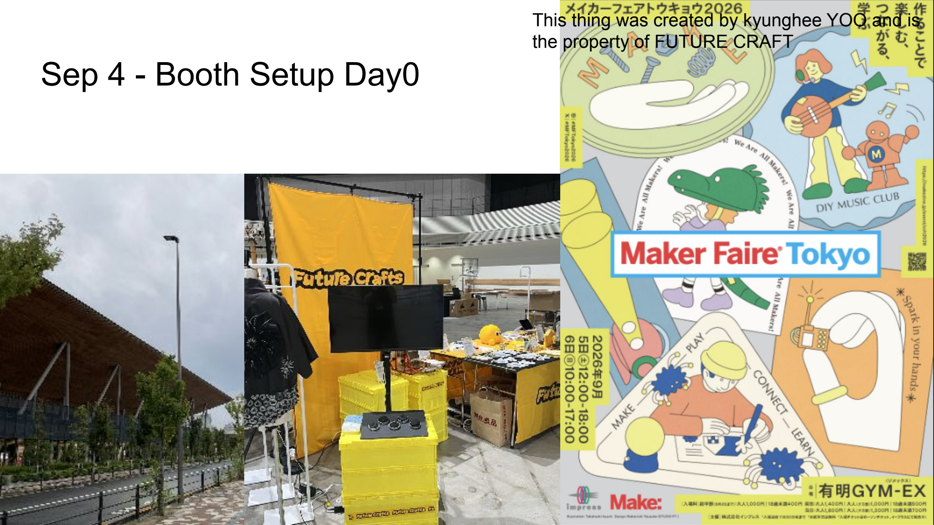
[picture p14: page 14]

the property of FUTURE CRAFT

# Sep 2, 3 - Modular Improvement 4

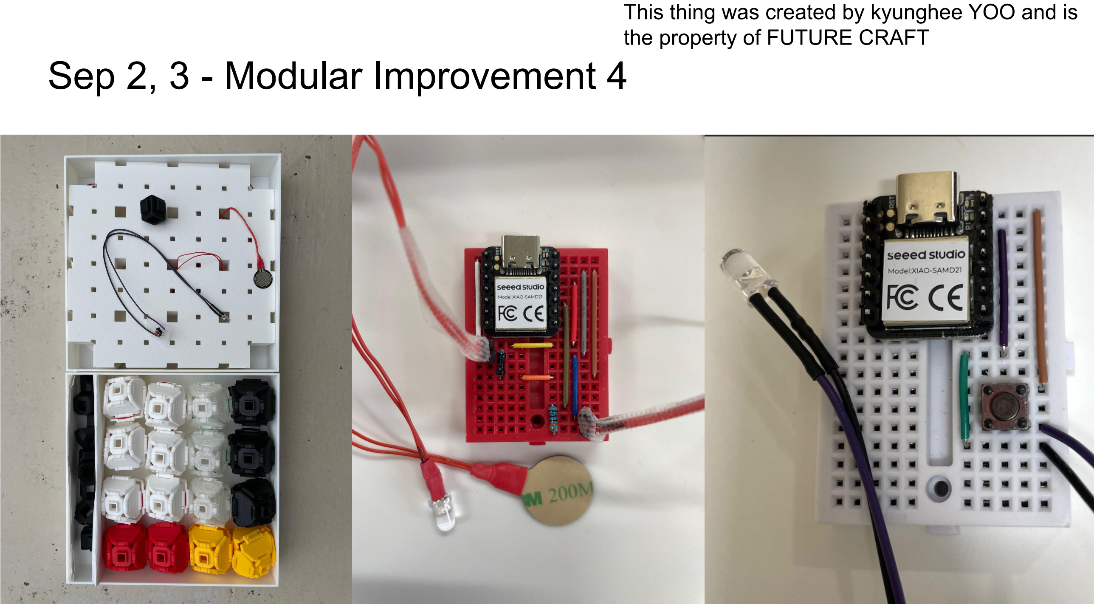
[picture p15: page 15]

the property of FUTURE CRAFT

Arduino code (Plato_001_fsr_led.ino)

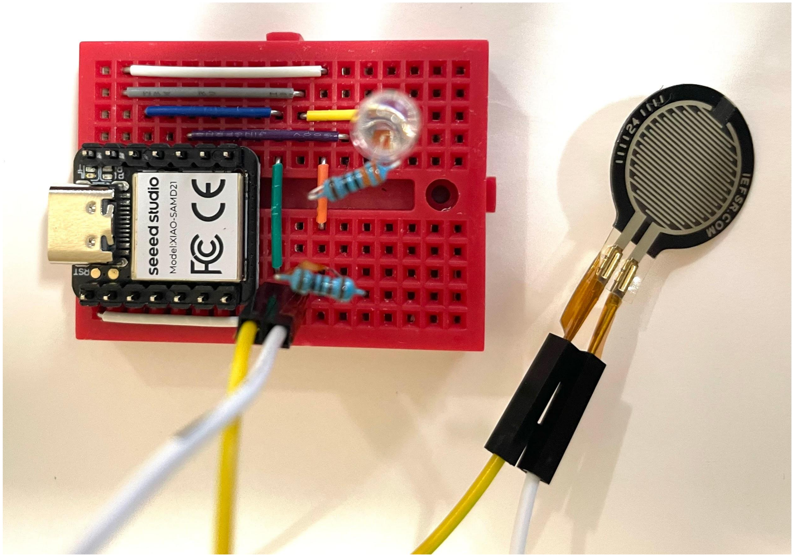
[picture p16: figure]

const | int | fsrPin = A0;
| const | int | ledPin = | 9;
const | float | R_FIXED = | 1000.0 ; | // 1kΩ
const | float | VCC = | 3.3; | // 3.3V | 로 변경
float | condMin = | 0.000007 | ;
float | condMax = | 0.001 ; | // | 실측 | 후 조정
void | setup () {

Serial .begin (9600);

pinMode (ledPin, OUTPUT);

pinMode (fsrPin, INPUT);

}

void | loop() {
int | raw = | analogRead | (fsrPin);
float | vOut = raw * (VCC / | 1023.0 );
float | conductance;
if | (vOut <= | 0.01) {
conductance = | 0;
} | else | {
| float | rFsr = R_FIXED * (VCC - vOut) / vOut;
conductance = | 1.0 | / rFsr;

}

int | brightness = ( | int)((conductance - condMin) / (condMax - condMin) * | | 255);
brightness = | constrain | (brightness, | 0, | 255);
analogWrite | (ledPin, brightness);
Serial .print ("raw: " ); | Serial .print (raw);
Serial .print ("\tconductance: " | ); | Serial .print (conductance, | 6);
Serial .print ("\tbrightness: " | ); | Serial .println (brightness);

delay (50);

}

the property of FUTURE CRAFT

# Sep 1 - Modular Improvement 3

Placement order (XIAO SAMD21, no-rail mini breadboard):

FSR circuit (chip's left side = A0)

1. Jumper wire from 3.3V-OUT pin (chip's right side) → empty row B
2. FSR402 leg 1 → row B (same row as the 3.3V jumper)
3. FSR402 leg 2 → empty row C
4. 1kΩ resistor leg 1 → row C (same row as FSR leg 2 — this is the voltage-divider junction)
5. 1kΩ resistor leg 2 → empty row D
6. Jumper wire from a GND pin (chip's right side) → row D (same row as resistor leg 2)
7. Jumper wire from A0 pin (chip's left side) → row C (the FSR–resistor junction — NOT row B)

LED circuit (chip's right side = D9)

8. Jumper wire from D9 pin → empty row E
9. 330Ω resistor leg 1 → row E (same row as the D9 jumper)
10. 330Ω resistor leg 2 → empty row F
11. LED anode (long leg) → row F (same row as resistor leg 2)
12. LED cathode (short leg) → empty row G
13. Jumper wire from a GND pin → row G (same row as LED cathode)

Key check: row C must contain exactly three things — FSR leg 2, 1kΩ resistor leg 1, and the A0 jumper. That's the voltage-divider tap point that was wrong before. Row B (power) and row G (LED ground) each need their own separate GND/3.3V jumper since this board has no shared rails.

the property of FUTURE CRAFT

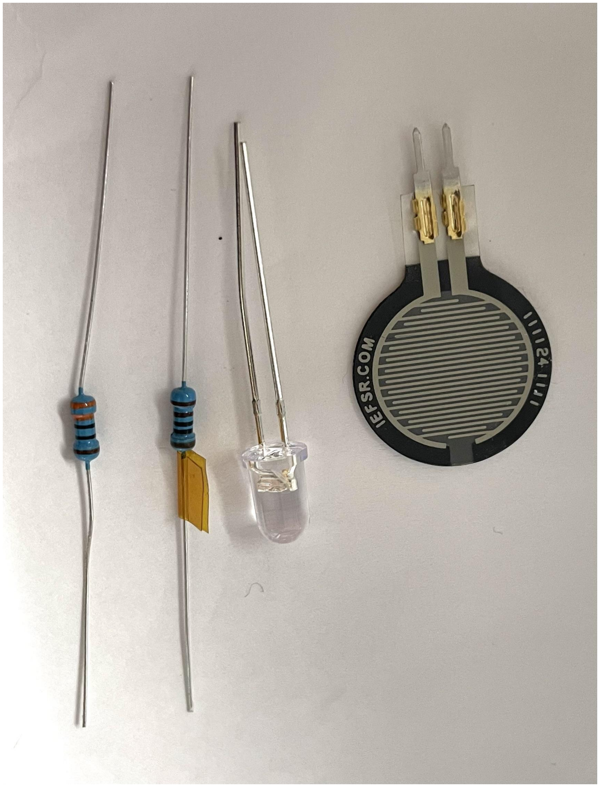
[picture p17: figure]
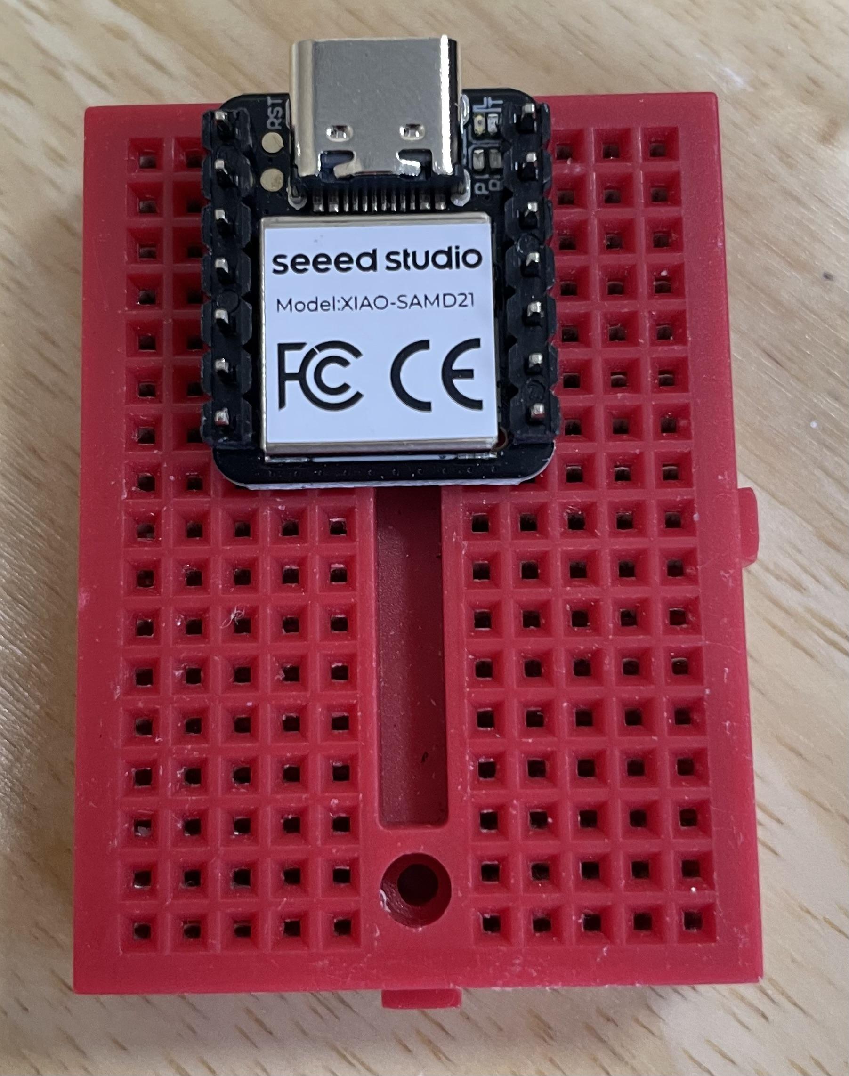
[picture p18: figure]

# Aug 31 - Modular Improvement 2

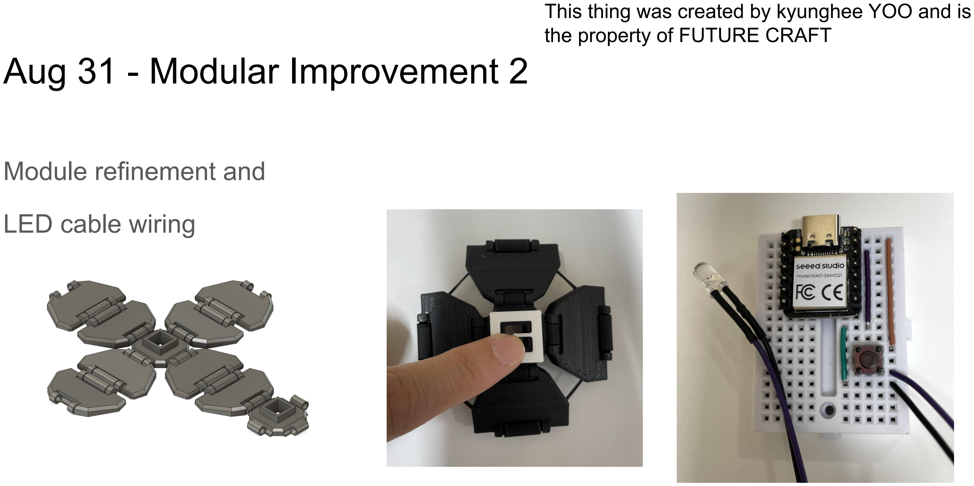
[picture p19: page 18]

## Module refinement and

## LED cable wiring

the property of FUTURE CRAFT

# Aug 29, 30 - Modular Improvement 1

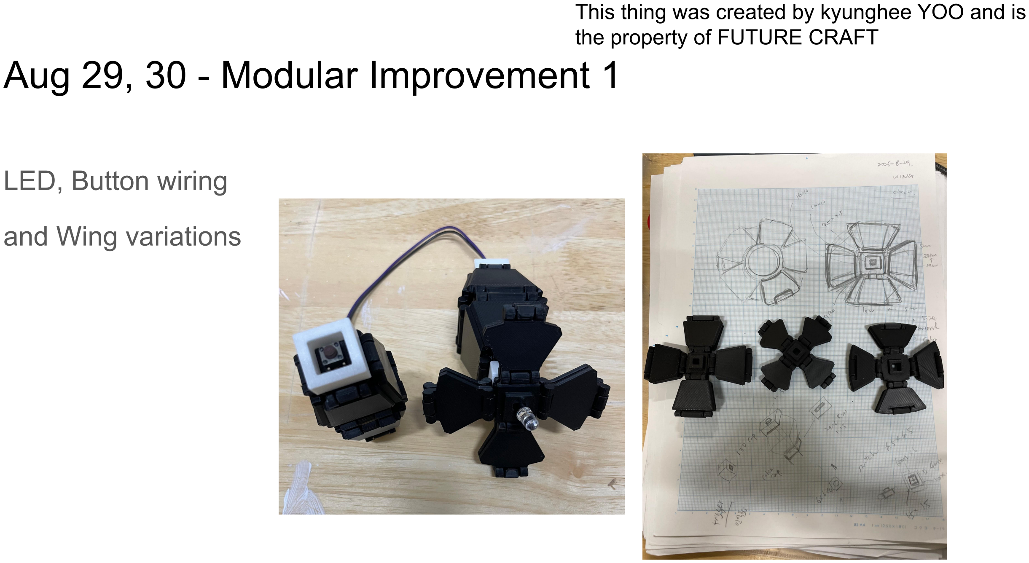
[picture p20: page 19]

## LED, Button wiring

## and Wing variations

the property of FUTURE CRAFT

Under time constraints,

I implement button and LED features.

# Aug 28 - Circuit Build

the property of FUTURE CRAFT

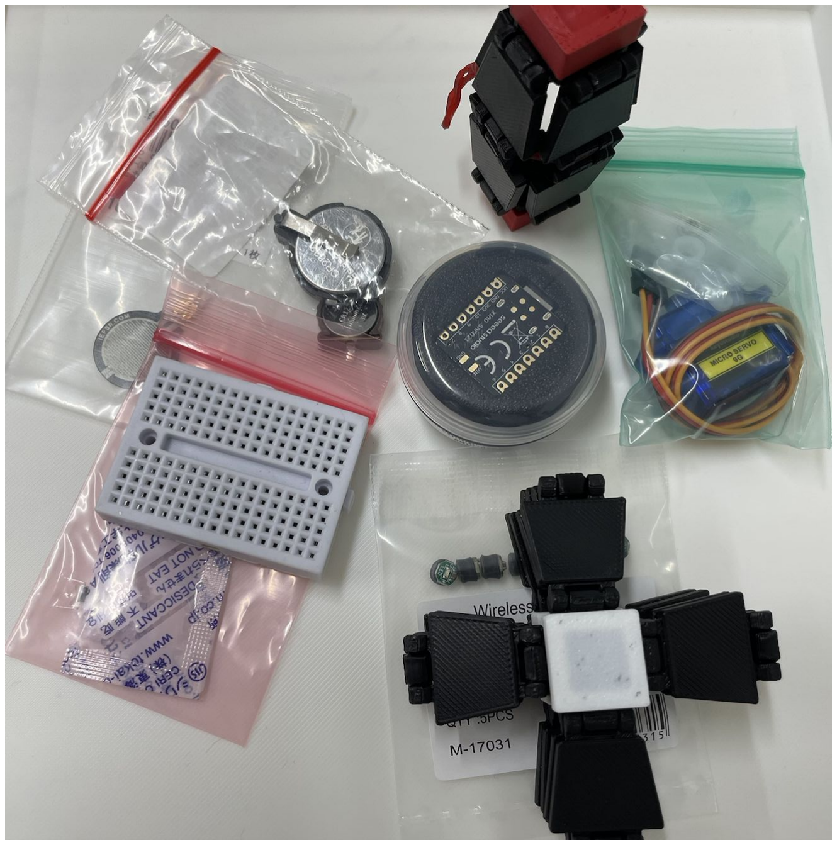
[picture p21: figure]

MCU | Seeed XIAO SAMD21
Sensor | Pressure, Photo diaod
Feedback | LED, Motor

# Aug 27 - Circuit Plan

the property of FUTURE CRAFT

# Aug 26 - Connector

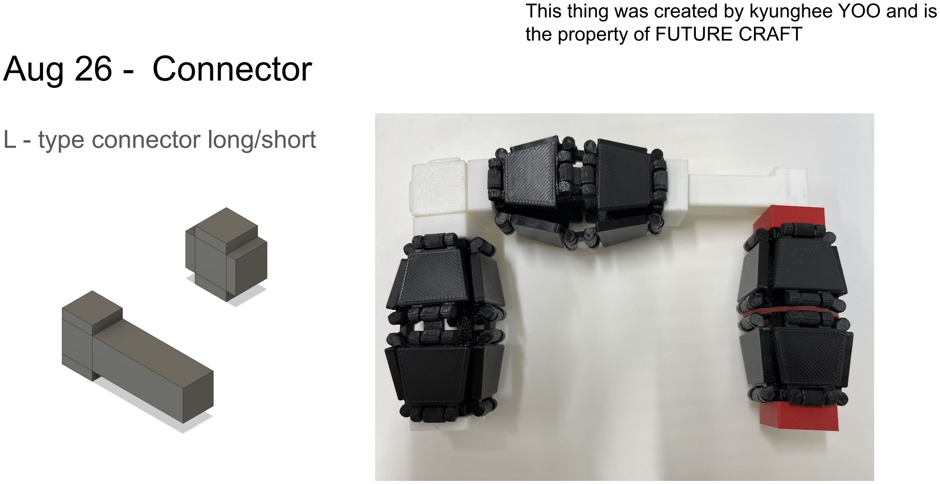
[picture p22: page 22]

## L - type connector long/short

the property of FUTURE CRAFT

# Aug 25 - MFT26 Layout

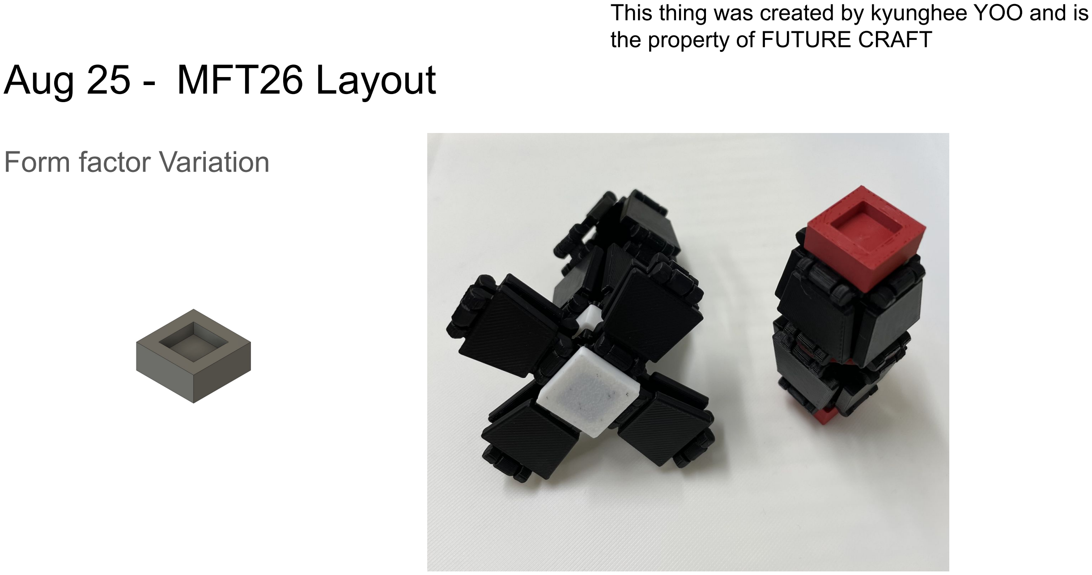
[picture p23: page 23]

## Form factor Variation

the property of FUTURE CRAFT

# Aug 24 - MFT26 Layout

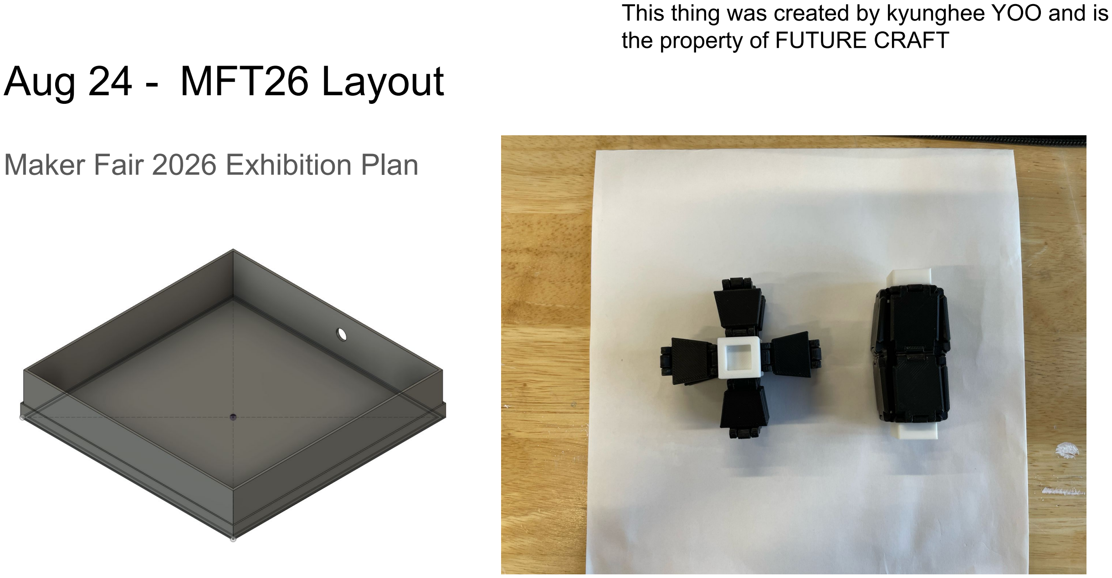
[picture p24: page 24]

## Maker Fair 2026 Exhibition Plan

the property of FUTURE CRAFT

# Aug 22 - Quadra trapezoid

## Trapezoid four wings with rubber band

the property of FUTURE CRAFT

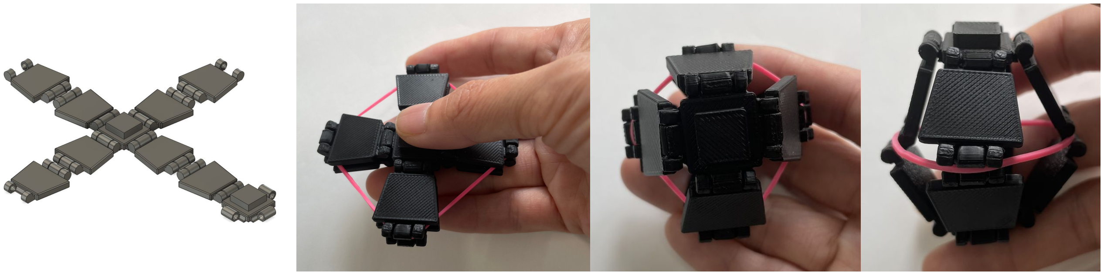
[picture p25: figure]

# Aug 21 - Quadra perpendicular

## Perpendicular four wings modular

the property of FUTURE CRAFT

# July 25 - Quadra

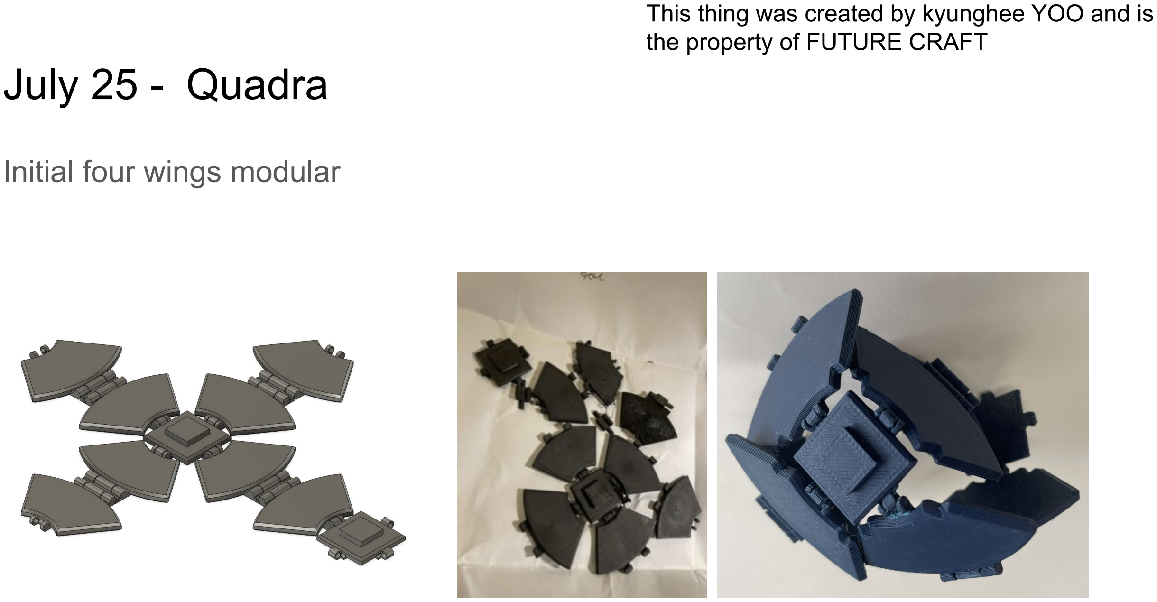
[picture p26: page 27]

## Initial four wings modular

the property of FUTURE CRAFT

# May 25 - FidgetSqueezer

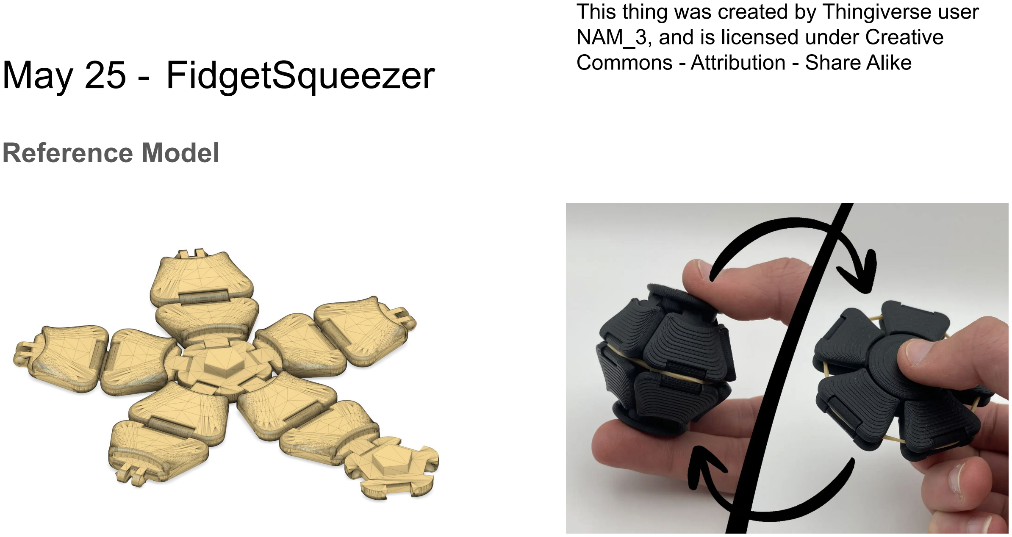
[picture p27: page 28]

## Reference Model

This thing was created by Thingiverse user NAM_3, and is licensed under Creative Commons - Attribution - Share Alike

# FUTURE CRAFT REAL PROJECT Maker Fair Tokyo 2026

# Kyunghee YOO 2026 Summer

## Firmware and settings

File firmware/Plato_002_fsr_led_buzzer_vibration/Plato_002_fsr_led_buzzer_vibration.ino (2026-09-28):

// Plato_002_fsr_led_buzzer_vibration.ino
//
// Extends Plato_001_fsr_led (the circuit exhibited at Maker Faire Tokyo
// 2026) with two more outputs, both active together once the FSR is
// pressed past a threshold: a buzzer, and a vibration-motor breakout
// module (driver built into the module, so its IN pin can be driven
// directly from a GPIO/PWM pin) shaking hard enough to rattle the printed
// plastic structure against itself - a stand-in "feel the resonance
// plate vibrating" haptic channel.
//
// The FSR->LED brightness mapping is unchanged from Plato_001 and stays
// continuously proportional to force. The buzzer is a discrete on/off
// chirp layer once pressed (see below); the vibration motor is a graded
// haptic layer - its intensity scales continuously with how hard you
// press (harder squeeze -> stronger felt vibration), not just on/off,
// so it reads as feeling the plate's own vibration rather than a single
// fixed buzz.
//
// Board: Tools > Board > Seeed SAMD Boards > Seeeduino XIAO
//
// Wiring (adds to the Plato_001_fsr_led breadboard - see that folder's
// README for the FSR/LED rows):
//   Buzzer - TMB12A05 (2-lead ACTIVE buzzer, built-in driver, fixed
//   ~2.4kHz internal tone, rated 4-8V/5V). Two things this is NOT: it is
//   not a passive piezo (tone()'s frequency argument can't set its pitch -
//   it always sounds at its own fixed ~2.4kHz), and it does not run off
//   the 3.3V rail (below its 4V minimum, so it likely won't oscillate at
//   all - this is the most likely reason the buzzer didn't work). Since
//   the MCU's GPIO HIGH is only 3.3V, it can't source the buzzer's
//   required 5V either, so it's wired as a low-side switch instead:
//     XIAO "5V" pin -> buzzer + lead   (SHORT lead - opposite of the LED
//                                        long-leg-is-anode convention;
//                                        needs the board powered over USB,
//                                        which is where that pin gets 5V)
//     buzzer - lead -> D8              (LONG lead; GPIO sinks current to
//                                        switch it on)
//   Control logic: D8 driven LOW (OUTPUT) sinks current, completing the
//   circuit (buzzer ON). For OFF, D8 is switched to INPUT (high-impedance)
//   rather than driven HIGH - driving it HIGH only leaves ~1.7V across the
//   buzzer (5V - 3.3V), and some active-buzzer driver ICs can *sustain*
//   oscillation at that leftover voltage even though they need the full 4V+
//   to *start* it, so a once-triggered buzzer never actually stops. Setting
//   D8 to INPUT removes the current path entirely (no meaningful voltage
//   across the buzzer at all), which reliably silences it without needing
//   an extra transistor as a true low-side switch.
//
//   Since this buzzer's ~2.4kHz tone/timbre is fixed in hardware and can't
//   be changed by software, "sounds harsh" is addressed by shaping the
//   on/off *rhythm* instead: rather than one continuous drone for the
//   whole press, the buzzer is pulsed into short chirps (BUZZ_ON_MS on,
//   BUZZ_OFF_MS off, repeating) while pressed, which reads as a soft
//   chirping/beeping pattern instead of a harsh flat tone. Each chirp's
//   OFF gap still goes through the same INPUT high-impedance trick above
//   (not HIGH), so it stays reliably silent between chirps too - PWMing
//   the sink pin instead (partial duty) was considered and rejected,
//   since the leftover voltage during the HIGH portion of a PWM cycle can
//   re-trigger the same "won't turn off" sustain behavior described above.
//   Tune BUZZ_ON_MS / BUZZ_OFF_MS to taste (shorter ON / longer OFF reads
//   as a lighter "tick"; longer ON / shorter OFF approaches a continuous
//   drone again). For a genuinely different pitch (e.g. closer to 600Hz)
//   or a smoother waveform, this active buzzer would need to be swapped
//   for a passive piezo (no built-in driver) driven with tone() - see this
//   folder's README.
//
//   Vibration motor module (3-pin breakout, driver already on the board):
//     D2 -> IN
//     3V3 -> VCC   (module is commonly rated 3-5V; expect a bit less punch
//                    at 3.3V than at 5V - bump towards 255 first if it
//                    feels weak before reaching for 5V)
//     GND -> GND
//
//   Haptic feel: this is a small ERM (eccentric rotating mass) motor, not
//   an LRA - its felt vibration frequency isn't independently settable,
//   it's a side effect of how fast the eccentric mass spins, which tracks
//   the applied voltage/PWM duty. So unlike the LED (which stays legible
//   across its whole 0-255 range), driving this motor anywhere below
//   roughly its rated voltage just makes it spin slower/weaker - it may
//   not even overcome its own static friction and spin up at all, giving
//   no felt vibration rather than a gentler one. To let a squeeze be felt
//   as a genuine "resonance plate is buzzing" sensation (and get it
//   reasonably close to its rated ~150-200Hz felt frequency, typical for
//   small coin ERM motors at rated voltage - re-measure if you know this
//   module's exact part number), intensity is mapped from
//   MIN_EFFECTIVE_VIBRATION..255 across the pressed force range instead of
//   0..255, so it never drops into that ineffective low band once pressed.

const int fsrPin = A0;
const int ledPin = 9;
const int buzzerPin = 8;
const int vibrationPin = 2;

const float R_FIXED = 1000.0; // 1k ohm
const float VCC = 3.3;        // XIAO SAMD21 runs its ADC/IO at 3.3V

// FSR402 conductance range observed on the bench; re-measure per physical
// build (see Plato_001_fsr_led/README.md's calibration section).
float condMin = 0.000007;
float condMax = 0.001;

const int PRESS_ON_BRIGHTNESS = 40;  // brightness (0-255) above which the buzzer+vibration turn on
const int PRESS_OFF_BRIGHTNESS = 20; // below which they turn back off
// (the gap between ON/OFF is hysteresis, so sensor noise right at the
// threshold can't make them chatter on and off rapidly)
// Small coin ERM motors typically need roughly 60-70% of their rated
// voltage just to start spinning at all, so intensity is scaled within
// this upper band instead of the full 0-255 range (see wiring note above).
const int MIN_EFFECTIVE_VIBRATION = 170; // PWM floor once pressed - below this it may not spin
const int MAX_VIBRATION = 255;           // PWM at full press force

const unsigned long SENSE_INTERVAL_MS = 50; // FSR read / LED update rate
// A too-short ON pulse cuts the buzzer off before its internal driver
// finishes ramping up to full volume, and a low ON/(ON+OFF) duty cycle
// lowers the averaged loudness on top of that - both made the first chirp
// version (25/70) noticeably quieter than the old continuous tone. 90/35
// keeps an audible pulsing texture (not a flat drone) while giving the
// driver enough ON time to reach full volume and raising the duty back up.
const unsigned long BUZZ_ON_MS = 90;  // each chirp's ON duration
const unsigned long BUZZ_OFF_MS = 35; // gap between chirps while pressed

bool pressed = false;
bool buzzChirpOn = false;
unsigned long lastSenseMs = 0;
unsigned long lastBuzzToggleMs = 0;

void setup() {
  Serial.begin(9600);
  pinMode(ledPin, OUTPUT);
  pinMode(fsrPin, INPUT);
  pinMode(buzzerPin, INPUT); // high-impedance = buzzer off (see wiring note above)
  pinMode(vibrationPin, OUTPUT);
}

void loop() {
  unsigned long now = millis();

  if (now - lastSenseMs >= SENSE_INTERVAL_MS) {
    lastSenseMs = now;

    int raw = analogRead(fsrPin);
    float vOut = raw * (VCC / 1023.0);

    float conductance;
    if (vOut <= 0.01) {
      conductance = 0;
    } else {
      float rFsr = R_FIXED * (VCC - vOut) / vOut;
      conductance = 1.0 / rFsr;
    }

    int brightness = (int)((conductance - condMin) / (condMax - condMin) * 255);
    brightness = constrain(brightness, 0, 255);
    analogWrite(ledPin, brightness);

    if (!pressed && brightness > PRESS_ON_BRIGHTNESS) {
      pressed = true;
    } else if (pressed && brightness < PRESS_OFF_BRIGHTNESS) {
      pressed = false;
    }

    if (pressed) {
      int vibrationIntensity = map(brightness, PRESS_ON_BRIGHTNESS, 255,
                                    MIN_EFFECTIVE_VIBRATION, MAX_VIBRATION);
      vibrationIntensity = constrain(vibrationIntensity, MIN_EFFECTIVE_VIBRATION, MAX_VIBRATION);
      analogWrite(vibrationPin, vibrationIntensity);
    } else {
      analogWrite(vibrationPin, 0);
    }

    Serial.print("raw: ");
    Serial.print(raw);
    Serial.print("\tconductance: ");
    Serial.print(conductance, 6);
    Serial.print("\tbrightness: ");
    Serial.print(brightness);
    Serial.print("\tpressed: ");
    Serial.println(pressed);
  }

  if (pressed) {
    if (buzzChirpOn && now - lastBuzzToggleMs >= BUZZ_ON_MS) {
      buzzChirpOn = false;
      lastBuzzToggleMs = now;
      pinMode(buzzerPin, INPUT); // silent gap between chirps
    } else if (!buzzChirpOn && now - lastBuzzToggleMs >= BUZZ_OFF_MS) {
      buzzChirpOn = true;
      lastBuzzToggleMs = now;
      pinMode(buzzerPin, OUTPUT);
      digitalWrite(buzzerPin, LOW); // sinks current, completing the 5V-fed buzzer's circuit
    }
  } else if (buzzChirpOn) {
    buzzChirpOn = false;
    pinMode(buzzerPin, INPUT); // high-impedance: no current path at all, so it's reliably silent
  }
}

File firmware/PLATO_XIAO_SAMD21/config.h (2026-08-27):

#pragma once

// ---- Serial transport (wired, interim pending the wireless decision) ----
// SAMD21 has no on-board radio, so this build streams over the native USB
// serial port instead of BLE. Each frame is [2 sync bytes, 3 bytes fold
// bitmask (LSB first), 1 flags byte] so the PC-side reader can stay
// byte-aligned on a continuous stream (unlike BLE notify, which is
// naturally framed per-packet); two marker bytes (vs. one) make an
// accidental match inside the bitmask itself far less likely to cause a
// false resync. If/when a BLE UART module is added, only the transport
// needs to change (see SerialTransport.*) - FlexMuxManager and
// HapticManager are unaffected.
#define SERIAL_BAUD 115200
#define SERIAL_SYNC_BYTE_1 0xAA
#define SERIAL_SYNC_BYTE_2 0x55

// ---- Flex sensor mux ----
// 20 flex sensors (one per hinge) read through two CD74HC4067 16-channel
// analog muxes sharing one ADC pin. Unlike ESP32C3, SAMD21 has no
// radio-vs-ADC pin conflict to work around - any pin works - but the wiring
// is kept identical to the ESP32C3 build for continuity with the physical
// harness.
#define MUX_ADC_PIN  0  // A0/D0
#define MUX_S0_PIN   1  // D1
#define MUX_S1_PIN   2  // D2
#define MUX_S2_PIN   3  // D3
#define MUX_S3_PIN   4  // D4
#define MUX_EN_A_PIN 5  // D5  - active-low enable, mux A = hinges 0-15
#define MUX_EN_B_PIN 6  // D6  - active-low enable, mux B = hinges 16-19

#define HAPTIC_PIN     7  // D7  - PWM to the haptic/ERM motor driver transistor
#define STATUS_LED_PIN 10 // D10 - lit while any hinge reads folded

#define MUX_SETTLE_US 50 // let the mux output settle before analogRead

// ---- Fold detection ----
// Normalized (0-1, from per-hinge calibration) threshold above which a
// hinge counts as "folded". Send 'c' over serial to (re)calibrate all 20
// hinges before each session - calibration is RAM-only (see
// FlexMuxManager) and needs re-running after every power cycle, which
// matches the documented per-session calibration protocol anyway.
#define FOLD_THRESHOLD 0.5f

// ---- Timing ----
#define SCAN_INTERVAL_MS        20    // ~50 Hz full 20-channel scan
#define NOTIFY_INTERVAL_MS      50    // ~20 Hz serial notify of the fold bitmask
#define CALIBRATION_DURATION_MS 15000 // hold-the-serial-command calibration window

// ---- Haptic feedback ("Block + haptic feedback" vs "Block motor-only") ----
// Toggle at runtime with the 'h' serial command so the same flashed
// firmware serves both conditions without reflashing between participants.
#define HAPTIC_ENABLED_DEFAULT true
#define HAPTIC_INTENSITY 180 // 0-255 PWM duty
#define HAPTIC_PULSE_MS  80  // vibration burst length per fold-state change

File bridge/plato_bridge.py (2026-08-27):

#!/usr/bin/env python3
"""Serial bridge for PLATO folding-block sensing nodes.

Reads the wired-USB fold-state stream from one or more XIAO SAMD21 PLATO
folding-block nodes (see firmware/PLATO_XIAO_SAMD21 - SAMD21 has no
on-board radio, so this is a wired interim transport pending a BLE-module
decision), logs it to a local CSV, and optionally git-commits the log
and/or forwards each row to a Google Sheet via an Apps Script Web App.
"""
from __future__ import annotations

import argparse
import csv
import os
import subprocess
import sys
import threading
from datetime import datetime, timezone
from pathlib import Path

import requests
import serial

# Must match SERIAL_SYNC_BYTE_1/2 and the payload layout in
# firmware/PLATO_XIAO_SAMD21/config.h and SerialTransport.cpp.
SYNC_BYTE_1 = 0xAA
SYNC_BYTE_2 = 0x55
PAYLOAD_LEN = 4

HINGE_COUNT = 20
CSV_FIELDS = ["timestamp_utc", "node", "haptic_active", "haptic_enabled"] + [
    f"hinge_{i:02d}" for i in range(HINGE_COUNT)
]


def decode_payload(data: bytes) -> dict:
    """Unpacks the firmware's 4-byte frame body: 3 bytes of 20-hinge fold
    bitmask (LSB first) + 1 flags byte (bit0 haptic active, bit1 haptic
    feedback condition enabled)."""
    if len(data) != PAYLOAD_LEN:
        raise ValueError(f"expected {PAYLOAD_LEN} bytes, got {len(data)}")
    bitmask = data[0] | (data[1] << 8) | (data[2] << 16)
    flags = data[3]

    reading = {
        "haptic_active": bool(flags & 0x01),
        "haptic_enabled": bool(flags & 0x02),
    }
    for i in range(HINGE_COUNT):
        reading[f"hinge_{i:02d}"] = int(bool(bitmask & (1 << i)))
    return reading


class Sink:
    """Fans out each reading to CSV, git, and/or Google Sheets."""

    def __init__(self, csv_path: Path, git_commit_every: int, sheets_url: str | None):
        self.csv_path = csv_path
        self.git_commit_every = git_commit_every
        self.sheets_url = sheets_url
        self._rows_since_commit = 0
        self._ensure_csv_header()

    def _ensure_csv_header(self) -> None:
        self.csv_path.parent.mkdir(parents=True, exist_ok=True)
        if not self.csv_path.exists():
            with self.csv_path.open("w", newline="") as f:
                csv.DictWriter(f, fieldnames=CSV_FIELDS).writeheader()

    def record(self, node: str, reading: dict) -> None:
        row = {"timestamp_utc": datetime.now(timezone.utc).isoformat(), "node": node}
        row.update(reading)

        with self.csv_path.open("a", newline="") as f:
            csv.DictWriter(f, fieldnames=CSV_FIELDS).writerow(row)

        if self.sheets_url:
            self._post_to_sheets(row)

        if self.git_commit_every:
            self._rows_since_commit += 1
            if self._rows_since_commit >= self.git_commit_every:
                self._rows_since_commit = 0
                self._git_commit()

    def _post_to_sheets(self, row: dict) -> None:
        try:
            requests.post(self.sheets_url, json=row, timeout=5)
        except requests.RequestException as exc:
            print(f"[sheets] post failed: {exc}", file=sys.stderr)

    def _git_commit(self) -> None:
        repo_dir = self.csv_path.resolve().parent
        try:
            subprocess.run(["git", "add", str(self.csv_path)], cwd=repo_dir, check=True)
            subprocess.run(
                ["git", "commit", "-m", f"Log PLATO sensor data ({datetime.now():%Y-%m-%d %H:%M})"],
                cwd=repo_dir,
                check=True,
            )
            subprocess.run(["git", "push"], cwd=repo_dir, check=True)
        except subprocess.CalledProcessError as exc:
            print(f"[git] commit/push failed: {exc}", file=sys.stderr)


def read_frames(ser: serial.Serial):
    """Generator that yields each frame's 4-byte payload, resyncing on the
    2-byte marker before every frame (cheap enough at ~20 Hz, and self-heals
    if a byte is ever lost/corrupted on the wire)."""
    while True:
        b = ser.read(1)
        if not b or b[0] != SYNC_BYTE_1:
            continue
        b2 = ser.read(1)
        if not b2 or b2[0] != SYNC_BYTE_2:
            continue
        payload = ser.read(PAYLOAD_LEN)
        if len(payload) != PAYLOAD_LEN:
            continue
        yield payload


def stream_node(port: str, baud: int, sink: Sink) -> None:
    node_name = port
    with serial.Serial(port, baud, timeout=1) as ser:
        print(f"[{node_name}] connected, streaming...")
        for payload in read_frames(ser):
            try:
                reading = decode_payload(payload)
            except ValueError as exc:
                print(f"[{node_name}] bad payload: {exc}", file=sys.stderr)
                continue
            sink.record(node_name, reading)
            folded = [i for i in range(HINGE_COUNT) if reading[f"hinge_{i:02d}"]]
            print(f"[{node_name}] folded={folded} haptic_active={reading['haptic_active']}")


def run(args: argparse.Namespace) -> int:
    sink = Sink(Path(args.csv), args.git_commit_every, args.sheets_url)

    ports = [p.strip() for p in args.ports.split(",") if p.strip()]
    if not ports:
        print("No serial ports given.", file=sys.stderr)
        return 1

    threads = [
        threading.Thread(target=stream_node, args=(port, args.baud, sink), daemon=True)
        for port in ports
    ]
    for t in threads:
        t.start()
    for t in threads:
        t.join()
    return 0


def parse_args() -> argparse.Namespace:
    parser = argparse.ArgumentParser(
        description="Serial bridge: PLATO folding-block node(s) -> CSV / git / Google Sheets"
    )
    parser.add_argument(
        "--ports",
        default="/dev/ttyACM0",
        help="comma-separated serial port(s), one per node (default: %(default)s)",
    )
    parser.add_argument("--baud", type=int, default=115200, help="must match SERIAL_BAUD in config.h")
    parser.add_argument(
        "--csv", default="data/plato_log.csv", help="local CSV log path (default: %(default)s)"
    )
    parser.add_argument(
        "--git-commit-every",
        type=int,
        default=0,
        help="commit+push the CSV every N new rows (0 = disabled)",
    )
    parser.add_argument(
        "--sheets-url",
        default=os.environ.get("GOOGLE_SHEETS_WEBHOOK_URL"),
        help="Google Apps Script Web App URL (or set GOOGLE_SHEETS_WEBHOOK_URL)",
    )
    return parser.parse_args()


if __name__ == "__main__":
    raise SystemExit(run(parse_args()))

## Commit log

2026-08-27 Add XIAO ESP32C3 Arduino firmware prototype (sensor, BLE, Wi-Fi, actuators)
    Modular sketch reading a BME280 over I2C and exposing it plus LED/servo/
    motor control through a shared JSON protocol on both a REST API (Wi-Fi)
    and a BLE GATT service (NimBLE-Arduino), with an arduino-cli profile and
    build/upload/monitor scripts.
    Claude-Session: https://claude.ai/code/session_016wn8mYbF3BQUaSMdWgE2fd
2026-08-27 Redesign firmware as an embedded bio+grip sensing node with a PC logging bridge
    Pivot from the generic actuator/BME280 demo to PLATO's actual research
    target: an FSR402 grip sensor plus an ambient-cancelled NJL5513R/BPW34 PPG
    pair embedded in a wirelessly-powered 3D structure, streaming over BLE only
    (no on-board Wi-Fi) to a new PC-side bridge that logs readings to CSV and
    optionally git-commits them and/or forwards them to a Google Sheet.
    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
    [PLATO_XIAO_C3.ino, config.h, plato_bridge.py]
2026-08-27 Redesign firmware for the 20-hinge folding-block device with haptic feedback
    Replace the bio-sensing node with the actual study apparatus: 20 flex
    sensors (one per hinge) read through two CD74HC4067 analog muxes sharing a
    single ADC pin, since XIAO ESP32C3 exposes only 3-4 ADC1 pins and adding
    external I2C ADC boards would be more hardware than needed. Adds per-hinge
    calibration (saved to NVS, triggered over serial) to bound the sensor
    variance flagged as an internal-validity concern, a non-blocking haptic
    driver for the Block+haptic condition (runtime-toggleable so one firmware
    image serves both study arms), and a compact 4-byte BLE payload so the
    20-hinge fold state always fits one notific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
    [FlexMuxManager.cpp, FlexMuxManager.h, PLATO_XIAO_C3.ino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]
2026-08-27 Add hardware/cad scaffolding for Fusion 360 exports
    Sets up a convention for versioning the folding-block design alongside the
    firmware: export neutral formats (STEP/STL/DXF) from Fusion 360 rather than
    committing its opaque native cloud file, name them by hinge-layout version,
    and keep hinge count in sync with FlexMuxManager::kChannelCount. Marks the
    CAD file extensions as binary in git to avoid noisy/broken diffs.
    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
2026-08-27 Add v0.1 folding-block STL export from Fusion 360
    First hardware export tracked in the repo, per the hardware/cad/README.md
    naming convention.
    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
    [plato-block_v0.1_2026-08-27.stl]
2026-08-27 Add v0.1 folding-block STEP export from Fusion 360
    STEP companion to the already-committed STL, so the design can be
    re-opened/edited in other CAD tools rather than only 3D-printed from mesh.
    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
    [plato-block_v0.1_2026-08-27.step]
2026-08-27 Add standalone SAMD21 exhibition build
    Separate, minimal firmware for the 7-day exhibition: the folding ball in
    this build moves as one open/closed degree of freedom (not 20 independent
    hinges), so it's a single flex sensor driving one LED's brightness, with
    auto-widening calibration (no manual reset needed across the exhibit run)
    and an idle "breathing" animation so the piece reads as alive when nobody's
    touching it. No wireless, no external libraries, kept fully separate from
    the ESP32C3 research firmware since board and purpose both differ.
    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
2026-08-27 Port research firmware from ESP32C3 to XIAO SAMD21
    The actual research board permanently moved to SAMD21, so
    firmware/PLATO_XIAO_C3/ (named and built for ESP32C3 specifically) no
    longer matched the real hardware. Renames it to firmware/PLATO_XIAO_SAMD21/
    and ports it:
    - Replace BleManager (NimBLE, ESP32/nRF-only) with SerialTransport: SAMD21
    has no on-board radio, so this streams the same 4-byte fold-state payload
    over wired USB serial instead, framed with a 2-byte sync marker so the PC
    reader can stay byte-aligned on a continuous stream. The wireless-vs-wired
    decision is still open; SerialTransport is the only file that would need
    to change to add a BLE UART module later.
    - Drop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
    [FlexMuxManager.cpp, FlexMuxManager.h, PLATO_XIAO_SAMD21.ino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]
2026-09-26 Replace guessed exhibit firmware with the actual Maker Faire circuit
    The uploaded MFT26 development log shows the real exhibited piece: an
    FSR402 + LED circuit on a bare XIAO SAMD21 (Plato_001_fsr_led.ino), part of
    "E. Modular" - a FidgetSqueezer-style folding ball, not the single flex
    sensor I'd guessed at earlier without seeing the actual build. Replaces
    firmware/PLATO_EXHIBIT_SAMD21/ with firmware/Plato_001_fsr_led/, using the
    exact validated code and breadboard wiring (FSR voltage-divider on A0, LED
    on D9) from the slide deck, and archives that deck at
    hardware/docs/MFT26_devlog.pdf for reference.
    Claude-Session: https://claude.ai/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
    [Plato_001_fsr_led.ino]
2026-09-26 Add buzzer + vibration motor as a second sensory layer (Plato_002)
    Extends Plato_001_fsr_led with the two components from the user's photos:
    a passive piezo buzzer (600 Hz fixed tone via tone()) and a vibration-motor
    breakout module (driver on-board, driven via PWM on its IN pin), both
    triggered together above a hysteresis threshold on the same FSR force
    reading that already drives the LED. Kept as a new numbered sketch rather
    than editing Plato_001_fsr_led, since that one is the historical record of
    what was actually exhibited.
    Notes the Chladni/Cymatics visual-pattern goal from the original plan isn't
    achievable with just these two components (needs an amplified signal into
    a rigid plate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
    [Plato_002_fsr_led_buzzer_vibration.ino]
2026-09-26 Add Fusion 360-importable wiring diagram for Plato_002
    Generates hardware/cad/plato_002_wiring_diagram.dxf with ezdxf: a 2D
    reference schematic (XIAO SAMD21, FSR402 divider, LED, buzzer, vibration
    motor module) on named layers, opens via Insert > Insert DXF into a Fusion
    360 sketch. Signal wires are routed through dedicated lanes above the
    components rather than straight across, so they don't visually cross
    through unrelated component bodies. Also fixes a stale
    firmware/PLATO_XIAO_C3 path reference in hardware/cad/README.md left over
    from the SAMD21 rename.
    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
    [plato_002_wiring_diagram.dxf]
2026-09-26 Add shared-rail breadboard wiring diagram and instructions for Plato_002
    Adds hardware/cad/plato_002_wiring_diagram_shared_rail.dxf: the same
    circuit as plato_002_wiring_diagram.dxf but redrawn for a standard
    breadboard with real +/- power rails instead of the no-rail mini board the
    firmware READMEs document. With shared rails the chip needs only one
    jumper to each rail total, instead of a separate point-to-point jumper
    back to the chip for every 3V3/GND use. Documents both the row-by-row
    no-rail placement order (continuing Plato_001's row lettering through the
    new buzzer/vibration components) and the simplified shared-rail version
    side by side in Plato_002's README, and explains the two DXF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
    [plato_002_wiring_diagram_shared_rail.dxf]
2026-09-28 Fix buzzer wiring/code: TMB12A05 is an active 5V buzzer, not passive
    Datasheet lookup confirms TMB12A05 is an active buzzer with a built-in
    driver and a fixed ~2.4kHz internal tone, rated 4-8V (5V nominal). This
    explains why it didn't work as wired: its + lead was on the 3.3V rail,
    below its minimum operating voltage, and tone(pin, 600) can't set an
    active buzzer's pitch anyway (it always sounds at its own fixed tone).
    Rewires it as a low-side switch fed from the XIAO's 5V pin (USB VBUS) with
    D8 sinking current on the - lead, and changes the firmware from
    tone()/noTone() to active-low digitalWrite(HIGH/LOW). Updates both wiring
    diagrams (no-rail and shared-rail) and the Plato_002 README to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
    [plato_002_wiring_diagram.dxf, plato_002_wiring_diagram_shared_rail.dxf]
2026-09-28 Document TMB12A05 lead polarity: short lead is +, long is -
    Confirmed via datasheet/community sources - opposite of the LED
    long-leg-is-anode convention, and an easy way to get the buzzer wired
    backwards (which can prevent it from working at all). Notes this at every
    point the +/- leads are mentioned: the .ino wiring comment and both wiring
    sections (no-rail and shared-rail) in the README.
    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
    [Plato_002_fsr_led_buzzer_vibration.ino]
2026-09-28 Add Plato_003_fsr_led_buzzer: FSR+LED+buzzer without the vibration module
    Same circuit and fixes as Plato_002_fsr_led_buzzer_vibration (TMB12A05
    active buzzer on the 5V pin, active-low control, short-lead-is-+ polarity
    note) but without the vibration motor module, for builds that only want
    sound feedback. Also fixes a stale "600 Hz piezo buzzer" description of
    Plato_002 in the top-level README (it's an active buzzer with a fixed
    ~2.4kHz tone, not a passive piezo at 600 Hz).
    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
    [Plato_003_fsr_led_buzzer.ino]
2026-09-28 Fix buzzer never turning off: switch to INPUT (high-Z) instead of HIGH
    The buzzer's driver IC can sustain oscillation at the ~1.7V left across
    it when D8 is driven HIGH (5V - 3.3V), even though it needs 4V+ to start
    oscillating. Switching D8 to INPUT for "off" removes the current path
    entirely instead, which reliably silences it without adding a transistor.
    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
    [Plato_002_fsr_led_buzzer_vibration.ino, Plato_003_fsr_led_buzzer.ino]
2026-09-28 Soften buzzer sound with a chirp pattern instead of a continuous drone
    TMB12A05's ~2.4kHz tone/timbre is fixed by its internal driver IC and
    can't be changed by software (tone()'s frequency argument does nothing
    here). Pulsing it into short on/off chirps instead of holding it on for
    the whole press reads as beeping rather than a harsh continuous buzz.
    Restructured the loop from a blocking delay(50) to millis()-timed
    scheduling so the chirp can run faster than the 50ms sensor sampling
    rate. Each chirp's off gap still uses the INPUT high-impedance trick
    (not HIGH) to avoid re-triggering the earlier "won't turn off" bug.
    Claude-Session: h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
    [Plato_002_fsr_led_buzzer_vibration.ino, Plato_003_fsr_led_buzzer.ino]
2026-09-28 Raise buzzer chirp duty cycle (90/35ms) so it's louder again
    25ms ON was quieter than the old continuous tone for two compounding
    reasons: a 26% duty cycle lowers time-averaged loudness, and 25ms may
    cut the pulse before the buzzer's internal driver ramps up to full
    amplitude. 90ms ON / 35ms OFF (72% duty) keeps an audible pulsing
    texture while restoring full volume.
    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
    [Plato_002_fsr_led_buzzer_vibration.ino, Plato_003_fsr_led_buzzer.ino]
2026-09-28 Make vibration motor a graded haptic layer proportional to press force
    The ERM vibration motor was previously a single fixed-intensity on/off
    output, mirroring the buzzer. Since its felt vibration frequency isn't
    independently tunable (unlike an LRA, it's just a function of spin
    speed/applied voltage), and small coin ERM motors need roughly 60-70%
    of rated voltage to start spinning at all, map intensity from
    MIN_EFFECTIVE_VIBRATION (170) to MAX_VIBRATION (255) across the pressed
    force range instead of a fixed value, so a light press still gives a
    felt buzz near its rated speed and a hard press gives the strongest one.
    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
    [Plato_002_fsr_led_buzzer_vibration.ino]
2026-11-05 Add Plato_004: servo slider-crank mechanism to physically lift the plate
    Extends Plato_002 with a fourth output using the SFE-ROB-14760 hobby
    servo as a slider-crank mechanism, raising/lowering the resonance plate
    while pressed instead of only buzzing/vibrating it. Lift speed scales
    with press force, matching the vibration motor's existing design. The
    servo only sweeps a limited arc (~160 deg rated), not full rotation, but
    a slider-crank doesn't need continuous rotation to produce reciprocating
    linear motion - same principle as a piston engine's crank.
    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
2026-11-05 Add slider-crank mechanism diagram for Plato_004
    Illustrates the servo-driven linkage (crank, connecting rod, vertical
    guide, slider, plate) with lowered/raised states overlaid and the key
    dimensions (crank radius, rod length, stroke) annotated.
    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
2026-11-05 Add Plato_004 lift mechanism parts DXF and step-by-step build guide
    DXF has flat profiles for the three custom 3D-printed parts (connecting
    rod, slider block, base bracket) for the servo slider-crank mechanism,
    with hole sizes/spacing annotated for Fusion 360 import. README gets a
    concrete assembly walkthrough (drilling the crank pin into the stock
    servo horn, seating guide rods, linkage assembly order, test-before-
    attaching-the-plate, and binding/jerkiness troubleshooting).
    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
2026-11-05 Add consolidated full build order checklist to Plato_004 README
    Sequences electronics wiring, firmware upload, mechanical assembly, and
    final testing into one ordered checklist, cross-referencing the detailed
    sections already in this and the Plato_001/002 READMEs instead of
    duplicating them.
    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
2026-11-05 Add Plato_005: tact switch toggle trigger for the servo lift, standalone
    Simplified build on a fresh breadboard: replaces the FSR with a
    debounced tact switch and drops LED/buzzer/vibration, keeping only the
    Plato_004 slider-crank lift mechanism. A press toggles the lift between
    running continuously at a fixed speed and stopped/at rest, instead of
    needing to be held - there's no analog force signal left to scale
    anything by once the FSR is gone.
    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
2026-11-05 Add wiring diagram for Plato_005 (tact switch + servo only)
    DXF schematic covering the simplified two-component circuit: XIAO pins,
    tact switch (INPUT_PULLUP, no external resistor), and the servo's three
    leads, with the shared GND junction marked and the 5V-not-3V3 power
    caveat noted. Same ezdxf/Fusion-360-import workflow as the existing
    Plato_002 wiring diagrams.
    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
2026-11-05 Add diagram showing where to drill the crank pin hole on the servo horn
    Clarifies the "drill 10mm from shaft center" build step with a visual:
    a generic X/cross servo horn with the measurement line and drill point
    marked, plus a note that the exact horn shape varies and to measure
    from the shaft center rather than the arm's own tip.
    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
2026-11-05 Expand the horn-zeroing build step with explicit sub-steps and test sketch
    The one-line "command it to SERVO_MIN_ANGLE before attaching the horn"
    instruction wasn't actionable on its own. Spells out why it matters
    (spline lets the horn attach at an arbitrary rotational offset, so
    without this step the firmware's angle and the horn's physical
    direction have no fixed relationship) and the concrete sequence,
    including a minimal throwaway test sketch to hold the servo at 20°.
    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
2026-11-05 Add dimensioned reference diagrams for the slider block and base bracket
    Same numbers as hardware/cad/plato_004_lift_parts.dxf, rendered as
    standalone illustrative diagrams (hole sizes, spacing, servo slot) in
    the same style as the crank pin drill diagram - easier to read at a
    glance than opening the DXF in Fusion 360.
    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
2026-11-05 Add diagram showing where the guide rods and slider sit in the assembly
    Side-view illustration clarifying the physical stacking: base bracket
    at the bottom with the two rods pressed into its rail holes, the
    slider block threaded onto those rods (shown lowered and raised), its
    connecting-rod pivot, and the plate mounted on top.
    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
2026-11-05 Add pivot joint diagram and expand the linkage-connection build step
    Explains the double-nut pivot construction used at both the crank pin
    and slider pivot: a lock nut tightened firmly against the fixed part,
    the rod's eyelet resting loosely on top, and a snug (not tight)
    retaining nut so it can still spin. Fixed step 2's wording, which
    previously said the crank pin's own nut should be "snug but still able
    to spin" - that free rotation actually happens at the rod's eyelet, not
    between the screw and the horn.
    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
2026-11-05 Fix base bracket servo slot size to match ROB-14760's real dimensions
    The DXF's placeholder slot (24x13mm) was narrower than the servo's
    actual body (28.8x13.8mm per SparkFun's listing) - widened to
    29.5x14.1mm (body + clearance). Added a diagram showing how the servo
    actually drops into the slot (shaft-up orientation, wire routing, glue
    points) and expanded the mounting build step with dry-fit guidance
    since 3D print tolerance varies by printer.
    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
2026-11-05 Add diagram and expand instructions for mounting the resonance plate
    Two options depending on the plate itself: screwed on (threaded insert
    or captured nut, for a flat drillable plate) or glued/taped on across
    the full contact area (for an irregular plate or one already part of
    the existing MFT26 structure, where drilling isn't an option).
    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
2026-11-05 Add a single full-assembly overview diagram tying all the detail diagrams together
    One combined side-view showing every part (base bracket + servo, horn/
    crank pin, connecting rod, slider block on its guide rods, resonance
    plate) in one picture, with each label pointing to the more detailed
    diagram that covers that part's specifics. Placed at the top of "How to
    build the mechanism" as the big-picture reference before the
    step-by-step instructions.
    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
2026-11-05 Add consolidated Bill of Materials for Plato_004
    Electronics, 3D-printed parts, mechanical hardware (with quantities),
    and consumables in one table, plus a per-build subset breakdown
    (Plato_001/002/003/004/005) since most of the list overlaps across
    builds. Linked from this README and the top-level README.
    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
